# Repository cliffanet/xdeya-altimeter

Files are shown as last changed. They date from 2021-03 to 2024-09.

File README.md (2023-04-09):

# Высотомер "Хде-Йа"

Инструмент для парашютиста - гибрид высотомера и Navi-возвращалки.

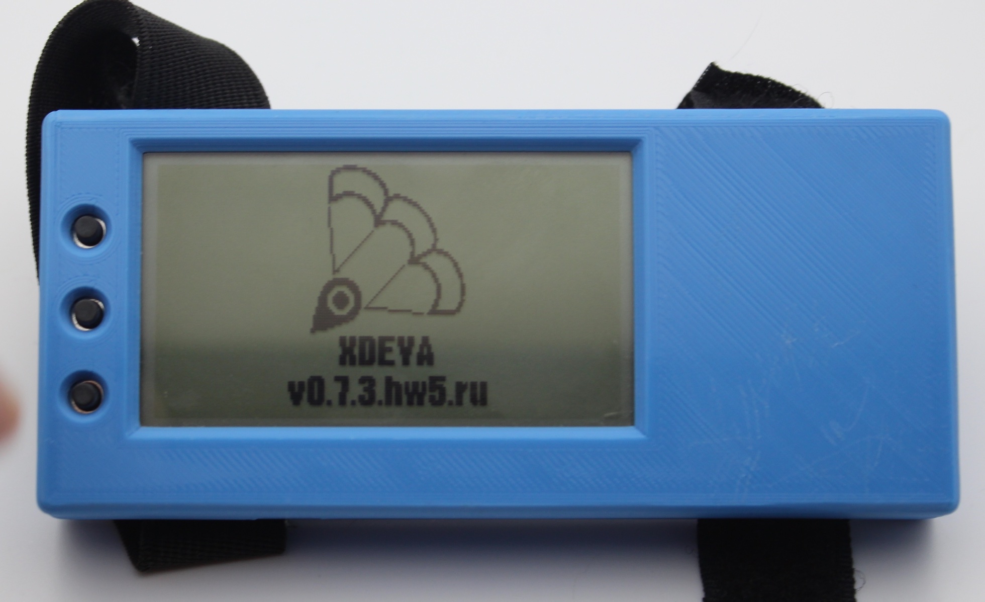
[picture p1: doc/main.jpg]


***
## Возможности

* Классические для высотомера: отображение высоты, логбук и т.д.
* Приём сигнала навигации (GPS + GLONASS)
* Отображение направления и расстояния до заранее сохранённой точки (возвращалка)
* Отображение вертикальной (по барометру) и горизонтальной (по навигации) скоростей
* В логбуке сохраняются показания высотомера и координаты на местности
* Запись трека со всеми имеющимися параметрами барометра и GPS/GLONASS-приёмника
* Взаимодействие с приложением (просмотр логбука, прыжков)

***
## Назначение

* Изначально устройство разрабатывалось как возвращалка в плохих метеоусловиях.

* Студенты, тренирующие точность приземления, смогут на земле разобрать прыжок, имея объективное средство контроля своих перемещений в пространстве.

* Мне как лот организатору групповых прыжков помогало контролировать точку выброски, сильно разгружая голову для остальных функций (взаимодействие с подопечными на борту, дополнительный контроль верности сигналов на выброску), а также помогая объективно оценить задержки выброски из-за неуспевания подготовиться вовремя к отделению.

* Инженеры, программисты микроконтроллеров, использующих Arduino и подобные средства разработки, найдут в этом устройстве полигон для экспериментов в воздухе.

>**Важно:** Устройство не может использоваться для тайного контроля за владельцем, т.к. передача данных вне устройства происходит только по запросу пользователя.

Впрочем, это открытый проект, и каждый может доработать Программное Обеспечение под свои нужды.

***
## Документация

* [Самое краткое руководство](doc/userman/simple/README.md) \[[PDF](doc/userman/xdeya-simple.pdf)|[Word](doc/userman/xdeya-simple.docx)\]
* [Как это сделать?](doc/userman/howdo/README.md) \[[PDF](doc/userman/xdeya-howdo.pdf)|[Word](doc/userman/xdeya-howdo.docx)\]
* [Описание Меню прибора](doc/userman/menu/README.md) \[[PDF](doc/userman/xdeya-menu.pdf)|[Word](doc/userman/xdeya-menu.docx)\]
* [Технические особенности и разъяснения](doc/userman/tech/README.md) \[[PDF](doc/userman/xdeya-tech.pdf)|[Word](doc/userman/xdeya-tech.docx)\]

* [Модификации](doc/models/README.md) - подробное описание аппаратных вариантов и их особенностей с фото.
* [Используемые комплектующие](doc/build/hardware.md)
* [Сколько стоит и где купить](doc/build/price.md)
* [Исходники](doc/code/README.md) - где, что лежит, права на использование, помощь при компиляции.
* [Где скачать](doc/download.md)

***

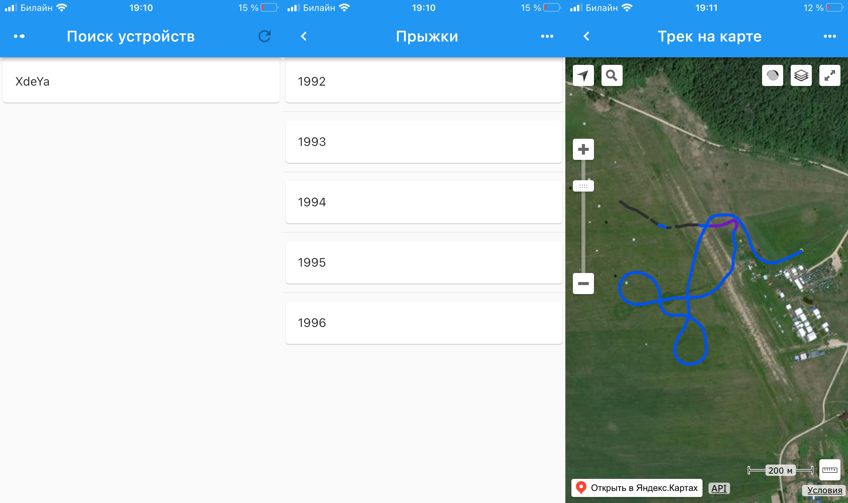
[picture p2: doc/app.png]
Приложение


<video width="475" controls title="demo">
  <source src="doc/demo.mp4" type="video/mp4">
</video>

***
## Контакты

Меня зовут Николай, веду проект `Высотомер + Навигация`. Связаться со мной можно:

* Telegram канал с информацией: [@xdeya](https://t.me/xdeya)
* Telegram: [Cliff](https://t.me/cliffa_net)
* cliff_mail@mail.ru
* Cайт проекта: [xdeya.ru](http://xdeya.ru)

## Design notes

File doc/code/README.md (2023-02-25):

# Хде-Йа - Исходники

## Открытость проекта

Проект полностью открыт. Закрывать - не планирую. На коммерческую основу ставить - не планирую.

Как минимум, для коммерции потребуются согласования по использованию в этом проекте исходного кода других разработчиков, а ещё сертификация использования GPS/GLONASS-приёмника и трекера.

[Репозиторий на github.com](https://github.com/cliffanet/xdeya-altimeter)

## Можно ли использовать исходники в своих проектах

Да, никаких возражений против использования исходного кода в своих проектах. Однако, будет лучше, если вы будете ссылаться на использование данного проекта. Это один из важных мотивационных факторов к дальнейшему развитию.

Это относится и к любительским проектам, и к крупным бесплатным, и к коммерческим.

## Где и что находится

* Исходный код прошивки

    Включает: директорию [`src`](https://github.com/cliffanet/xdeya-altimeter/tree/master/src), файлы [`def.h`](https://github.com/cliffanet/xdeya-altimeter/blob/master/def.h) и [`xdeya-altimeter.ino`](https://github.com/cliffanet/xdeya-altimeter/blob/master/xdeya-altimeter.ino). Для компиляции в среде Arduino нужно только это.
    
    Есть ещё скрипт [`fw`](https://github.com/cliffanet/xdeya-altimeter/blob/master/fw) - он написан на языке [perl](https://www.perl.org/) и служит для удобства компиляции и загрузки прошивки из консоли с помощью утилиты arduino-cli. Про это подробно расписано в подразделе [Как собрать исходный код у себя](#как-собрать-исходный-код-у-себя)

* Исходники электрической схемы и печатной платы

    Всё находится в директории [`hw`](https://github.com/cliffanet/xdeya-altimeter/tree/master/hw). Среда разработки: [KiCad EDA](https://www.kicad.org/)

* Исходники 3D-моделей для печати корпуса

    Директория [`box`](https://github.com/cliffanet/xdeya-altimeter/tree/master/box). Среда: [SketchUp](https://www.sketchup.com/ru)
    
    В имени skp-файла может встречаться `noroundcorner` - это исходник без скруглённых краёв. Оставлен, чтобы было проще поправить, а скругление краёв я всегда делаю в самом конце, т.к. отменить это действие никак нельзя. Файл xdeya.skp - это тот же файл, но  уже конечный вариант со скруглением.
    
    Тут же лежат экспортированные в `stl` файлы моделей. В имени файлов зашифровано:
    
    * `top` / `bottom` - верхняя и нижняя часть корпуса
    * `cord` / `lent` - крепление под эластичный шнур или под эластичную ленту
    * `long` - удлинённый корпус
    * `bold` - утолщённый корпус для более жирного аккумулятора

* Архив
    
    Директория [`arch.hw`](https://github.com/cliffanet/xdeya-altimeter/tree/master/arch.hw). Тут лежат исходники под различные модификации: `плата` (включая gerber-файлы для печати) и `корпус`.

## Электронные компоненты:

* Дисплей JLX19292G: COG 192x96 на чипе ST75256 c 24-pin шлейфом ([например](https://aliexpress.ru/item/1005002157371258.html))

## Как прошить с помощью программатора

### Подключение к компьютеру (версия v.0.3)

Вам потребуется переходник USB-to-UART, т.к. в устройстве его нет. Подойдёт любой с AliExpress.

На плате устройства есть вот такой разъём:

* `gnd` - к `GND` переходника.
* `3v3` - к выходу питания `+3.3v` переходника. Этот вывод можно и не подключать, а питать устройство от аккумулятора или через разъём MicroUSB.
* `tx` - к `RX` переходника.
* `rx` - к `TX` переходника.

При подключении переходника USB-to-UART к компьютеру в списке устройств должен появиться новый последовательный порт (COM-порт). Если этого не произошло, скорее всего, необходимо установить драйверы для этого переходника.

Для программирования данного устройства его надо перевести в download-режим. Для этого удерживая кнопку `boot` на плате устройства, нажмите и отпустите кнопку `reset`. После этого можно отпускать кнопку `boot`.

Теперь устройство готово к загрузке на него прошивки.

### Подключение к компьютеру (версия v.0.4 и более поздние)

У этой модификации на борту уже есть переходник USB-to-UART, поэтому для подключения к компьютеру достаточно подключить его кабелем через разъём MicroUSB на устройстве.

При подключении устройства к компьютеру через USB-кабель, в списке устройств должен появиться новый последовательный порт (COM-порт). Если этого не произошло, потребуется установить драйвер для чипа CP2102 под вашу операционную систему.

Теперь устройство готово к загрузке прошивки.

### Загрузка прошивки на устройство

* Берём [готовый файл](https://github.com/cliffanet/xdeya-altimeter/releases) прошивки (один нужной версии)

* Дополнительные файлы прошивки

    для Flash 4MByte: [boot.zip](https://github.com/cliffanet/xdeya-altimeter/raw/master/boot.zip)

    для расширенной Flash 16Mbyte: [boot.v6.zip](https://github.com/cliffanet/xdeya-altimeter/raw/master/boot.v6.zip)

* Скачиваем и запускаем [Flash Download Tools](https://www.espressif.com/en/support/download/other-tools)

* Нажимаем кнопку `ESP32`

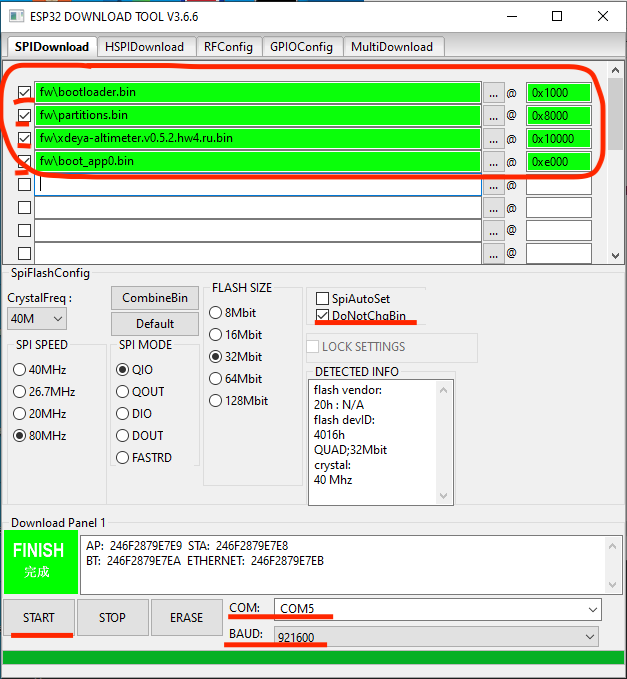
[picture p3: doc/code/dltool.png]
Espressif Flash Download Tools


* Указываем 4 файла и адреса к ним:

    * `bootloader.bin` - адрес 0x1000
    * `partitions.bin` - адрес 0x8000
    * `boot_app0.bin` - адрес 0xe000
    * основной файл прошивки - адрес 0x10000

* Ставим галку DoNotChgBin.

* Выбираем COM-порт, через который подключено устройство.

* BAUD : Это скорость, на которой будет заливаться прошивка. Должна работать любая, в т.ч. максимальная. Но может оказаться, что при высоких скоростях запись будет прерываться.

* Жмем кнопку `START`

После этого начнётся процесс заливки прошивки.

Для аппаратной версии [v.0.3](../models/01.v.0.3.md) для запуска устройства после заливки прошивки требуется нажать кнопку `reset`.

Для аппаратной версии [v.0.4](../models/02.v.0.4.md) ничего дополнительно не требуется.

## Как собрать исходный код у себя

### Используемые сторонние библиотеки для среды Arduino

* [Adafruit_BMP280_Library](https://github.com/adafruit/Adafruit_BMP280_Library)
* [Adafruit_BusIO](https://github.com/adafruit/Adafruit_BusIO) `ver1.9.6` (Необходимая зависимость для Adafruit_BMP280_Library)
* [Adafruit_Unified_Sensor](https://github.com/adafruit/Adafruit_Sensor) (Необходимая зависимость для Adafruit_BMP280_Library)
* [RTClib](https://github.com/adafruit/RTClib)
* [U8g2](https://github.com/olikraus/u8g2)

### В среде Arduino

* Используемая плата: ESP32 Dev Module

    В настройках среды Arduino в поле `Дополнительные ссылки для Менеджера плат` добавить:
    
    https://raw.githubusercontent.com/espressif/arduino-esp32/gh-pages/package_esp32_dev_index.json
    
    В Менеджере плат найти esp32 и установить версию 2.0.0
    
    **ВНИМАНИЕ** В версии 2.0.1 есть бага, при которой повторная WiFi-синхронизация вызывает перезагрузку устройства.

* Откройте в Arduino файл xdeya-altimeter.ino
* Компилируйте, загружайте

### С помощью arduino-cli

Этот способ не работает в Windows, т.к. там нет привычного shell.

Потребуются:

* установленные для Arduino библиотеки
* установленная для Arduino плата
* arduino-cli
* perl

Для компиляции используется скрипт [`fw`](../../fw), который находится в этих исходниках.

Пример запуска:

    ./fw compileupload 4 ru /dev/cu.SLAB_USBtoUART

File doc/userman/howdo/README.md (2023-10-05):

# Хде-Йа - Как это сделать?

## Разделы

* [Включение/Выключение](01.power.md)
* [Навигация](02.navigation.md)
* [Запись трека](03.track.md)
* [Синхронизация](04.syncronization.md)
* [Обновление ПО](05.firmware.md)
* [Системные операции](06.system.md)

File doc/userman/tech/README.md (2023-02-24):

# Хде-Йа - Технические особенности и разъяснения

## Разделы

* [Высотомер](01.altimeter.md)
* [Навигация](02.navigation.md)
* [Режимы питания](03.power.md)

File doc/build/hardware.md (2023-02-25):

# Хде-Йа - Выбранные чипы

## Основной микропроцессор

Сейчас в качестве центрального микроконтроллера используется чипсет [`esp32 wroom`](https://www.espressif.com/en/products/modules/esp32). Он часто применяется в разработках устройств умного дома, поэтому широко известен за свою простоту в использовании.

Причины, по которым изначально выбран именно этот чип:

* Хороший опыт работы с этим микроконтроллером
* Наличие WiFi и BlueThooth на борту
* Большой объём RAM и ROM памяти
* Простота программирования
* Широкое использование начинающими программистами микроконтроллеров (из-за низкого порога вхождения)

Всё это позволяет минимизировать затраты на разработку.

Однако, есть и минусы:

* Большие габариты
* Высокое энергопотребление
* Пока ещё сырое SDK от разработчиков чипа, особенно в области низкого энергопотребления и WiFi/BlueTooth

## Навигация

В данном устройстве используется навигационный чип [u-blox M8N](https://www.u-blox.com/en/product/neo-m8-series). Чип настроен на приём GPS и GLONASS сигналов.

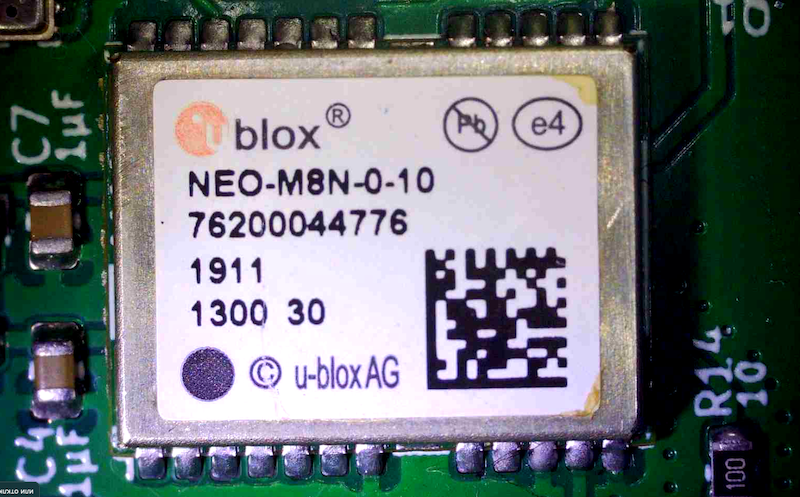
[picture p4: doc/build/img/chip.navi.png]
u-blox M8N


## Барометр

Для определения высоты применён барометрический чип [BMP280](https://www.bosch-sensortec.com/products/environmental-sensors/pressure-sensors/bmp280/), зарекомендовавший себя при разработке высотомеров у многих проектировщиков таких устройств.

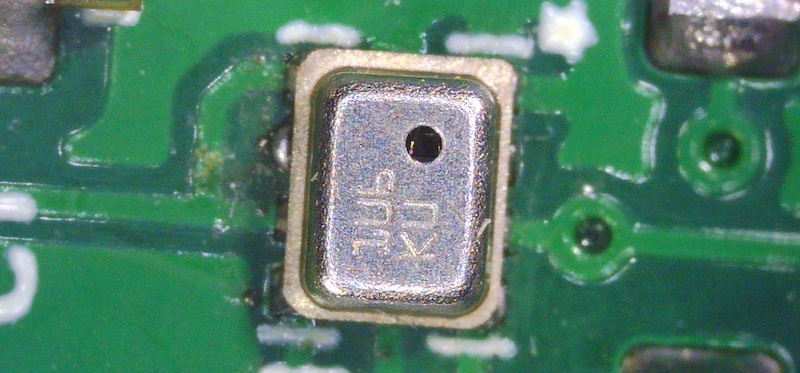
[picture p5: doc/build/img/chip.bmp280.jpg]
BMP280


## Компас

Используемый чип: LSM303DLH (именно с такими буквами, в корпусе LGA-28L).

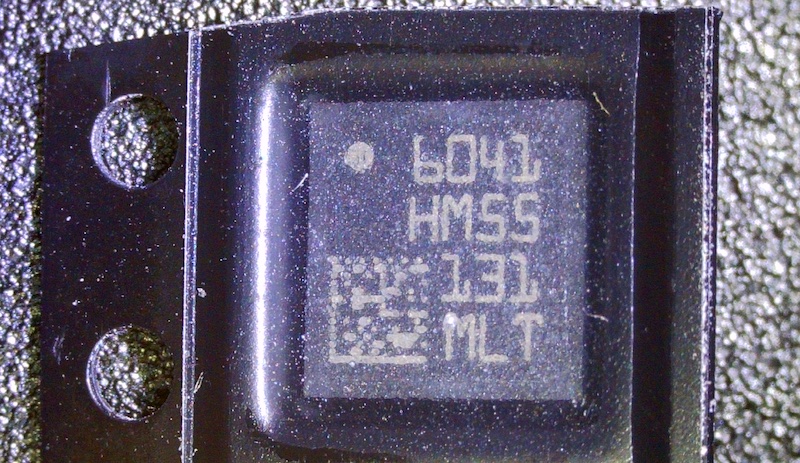
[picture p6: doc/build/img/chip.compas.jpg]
LSM303DLH


В его составе:

* Магнетометр - для определения вектора магнитных линий земли.
* Акселерометр - для определения положения прибора относительно Земли, чтобы корректно спроецировать вектор магнитного поля на поверхность Земли.

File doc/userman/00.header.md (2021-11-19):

---
title: "Хде-Йа - Руководство пользователя"
author: Cliff
geometry: margin=1.5cm
mainfont: Arial
monofont: PT Mono
toc-title: Оглавление
colorlinks:
    urlcolor: NavyBlue
    toccolor: Red
subparagraph: true
lang: ru-RU
---

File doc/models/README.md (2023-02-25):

# Хде-Йа - Разновидности устройств

На данный момент есть несколько вариантов устройств. Для каждого разработана своя плата, компановка деталей, корпус.

[Исходники](../code/README.md) всей технической документации можно скачать и использовать.

* [`v.0.3`](01.v.0.3.md) (более не поддерживается)
* [`v.0.4`](02.v.0.4.md) (более не поддерживается)
* [`v.0.5`](03.v.0.5.md)

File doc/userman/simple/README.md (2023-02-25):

# Знакомство

Вы никогда не задавались вопросом:

> И `хде йа` нахожусь?!

Или может в 2 часа ночи интересовались:

> Как пройти в библиотеку?

**Привет!**

Я - `высотомер` и `GPS/GLONASS` в одном приборе.

Я `**НЕ**` являюсь навигатором. Только возвращалкой к заранее заданной точке. Покажу направление и расстояние до точки по прямой.

Пока я ещё как эксперементальная разработка. Жить этому проекту или нет, выберете Вы сами.

А по карте маршрут вам проложит Яндекс Навигатор, но не я!

## Функции устройства

* Классические для высотомера: отображение высоты, логбук и т.д.
* Приём сигнала навигации (GPS + GLONASS)
* Отображение направления и расстояния до заранее сохранённой точки (возвращалка)
* Отображение вертикальной (по барометру) и горизонтальной (по навигации) скоростей
* В логбуке сохраняются показания высотомера и координаты на местности
* Запись трека со всеми имеющимися параметрами барометра и GPS/GLONASS-приёмника
* Синхронизация по WiFi (по запросу пользователя): отправка логбука, треков, приём некоторых настроек с сервера

# Диаграмма управления

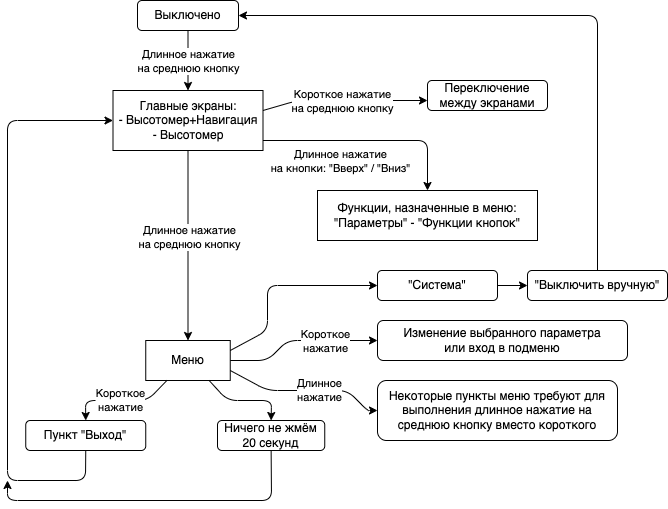
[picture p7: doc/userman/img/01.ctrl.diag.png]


# Органы управления

Переключение между страницами на главном экране - нажатие на `среднюю кнопку`.

Кнопки `Вверх` и `Вниз` работают только по `длинному нажатию`, их функциями можно управлять в меню `Параметры` -> `Функции кнопок`.

##  Экран: Навигация + Высотомер

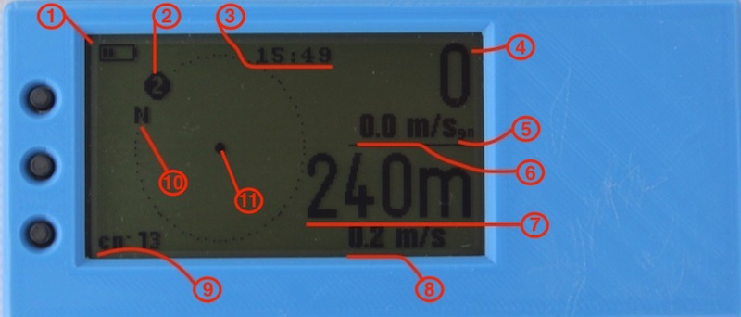
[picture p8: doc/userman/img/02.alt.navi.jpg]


1. Индикатор заряда батареи.
2. Относительное отображение расположение точки.
3. Текущее время (синхронизируется по GPS/GLONASS-сигналу).
4. Высота по барометру (метры).
5. Временное отображение режима высотомера (по текущей высоте, скорости и вертикальному направлению движения).
6. Вертикальная скорость (м/с).
7. Расстояние до выбранной точки (метры или километры).
8. Горизонтальная скорость.
9. Режим работы Navi приёмника (во включенном состоянии отображает число найденных спутников).
10. Условное обозначение "Севера".
11. Центр карты: тут мы, при движении рисуется стрелка - чем быстрее, тем длиннее.

##  Экран: Навигация

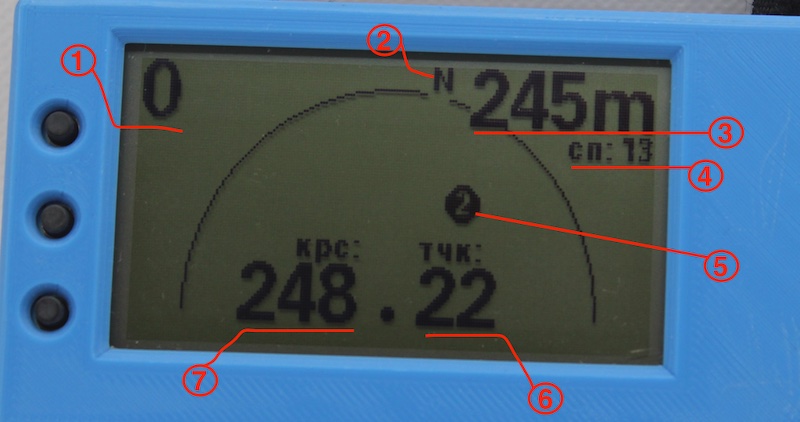
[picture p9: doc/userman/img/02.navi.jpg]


1. Высота по барометру (метры).
2. Условное обозначение "Севера".
3. Расстояние до выбранной точки (метры или километры).
4. Режим работы Navi приёмника (во включенном состоянии отображает число найденных спутников).
5. Относительное отображение расположение точки.
6. Направление до точки (в градусах).
7. Направление движения (в градусах).

## Экран: Высотомер

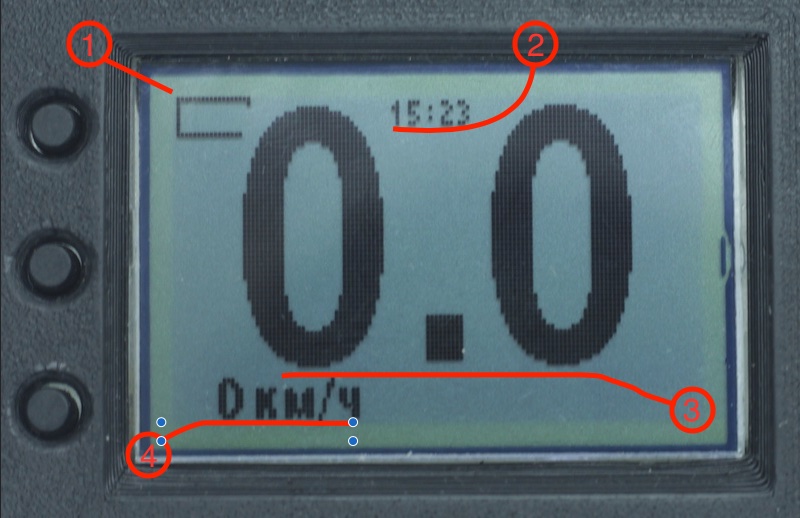
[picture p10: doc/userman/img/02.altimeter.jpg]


1. Индикатор заряда батареи.
2. Текущее время (синхронизируется по GPS/GLONASS-сигналу).
3. Высота по барометру (километры).
4. Вертикальная скорость (км/ч).

# Как вбить конечную точку

Меню: `Navi-точки` - выбираем из трёх слотов хранения координат и сохраняем текущее местоположение.

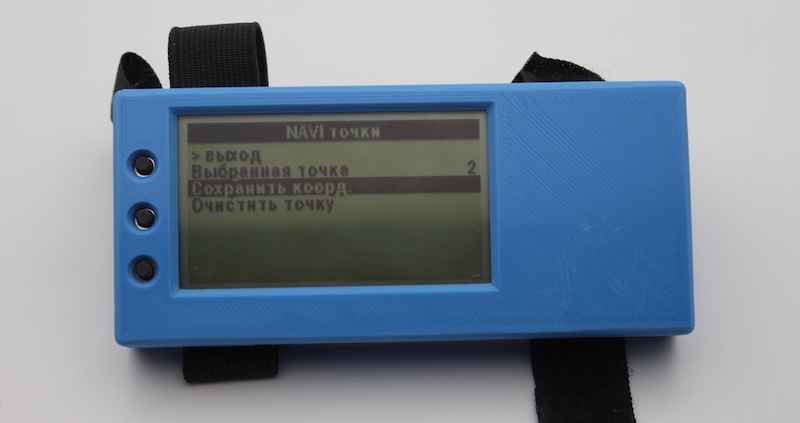
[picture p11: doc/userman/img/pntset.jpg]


# Как заряжать

В это отверстие вставляем USB-шнурок одним концом, а другим в зарядку или ваш домашний компьютер:

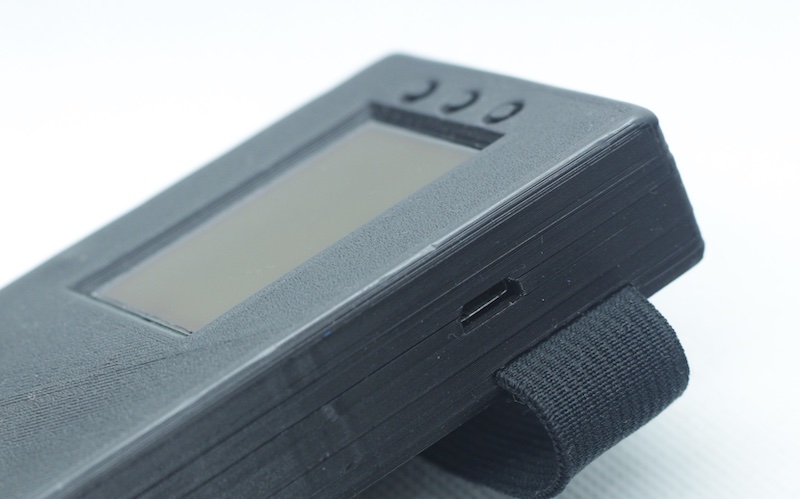
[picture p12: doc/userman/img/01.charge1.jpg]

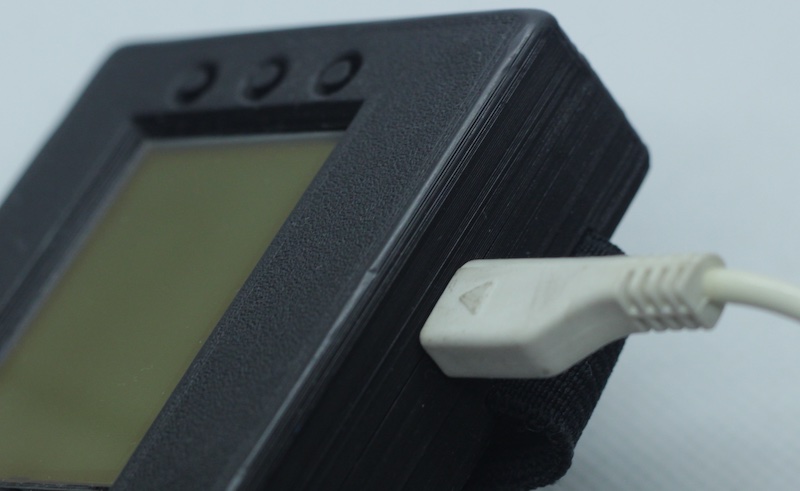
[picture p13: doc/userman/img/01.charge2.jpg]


# Крепление

* На руку

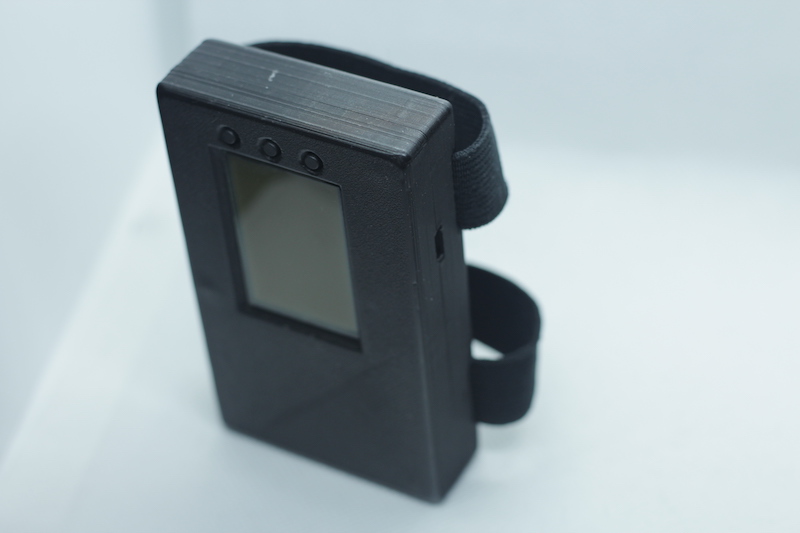
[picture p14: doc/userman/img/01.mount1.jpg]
Крепление на руку


* На ногу

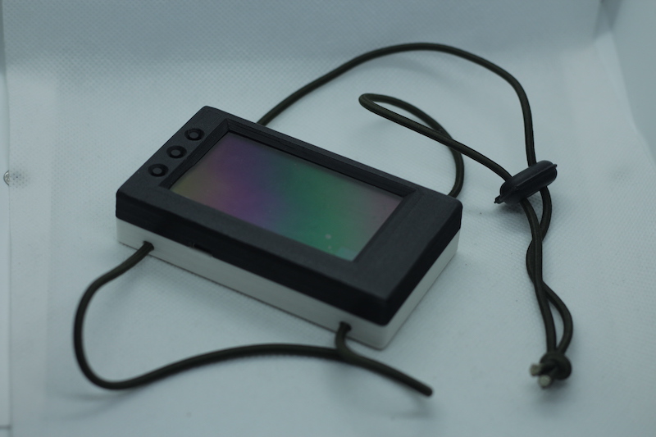
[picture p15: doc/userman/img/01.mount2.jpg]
Крепление на ногу


# Подсветка

Меню: `Параметры` -> `Дисплей` -> `Подсветка`

Для ночных прыжочков:

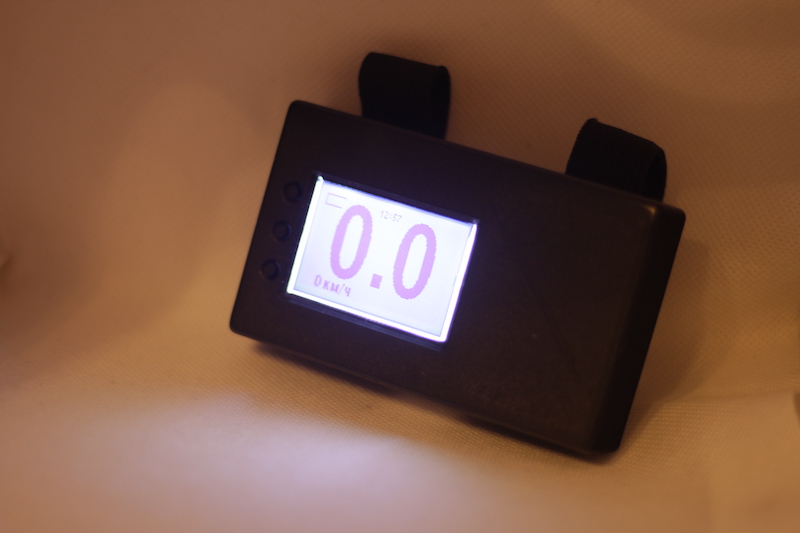
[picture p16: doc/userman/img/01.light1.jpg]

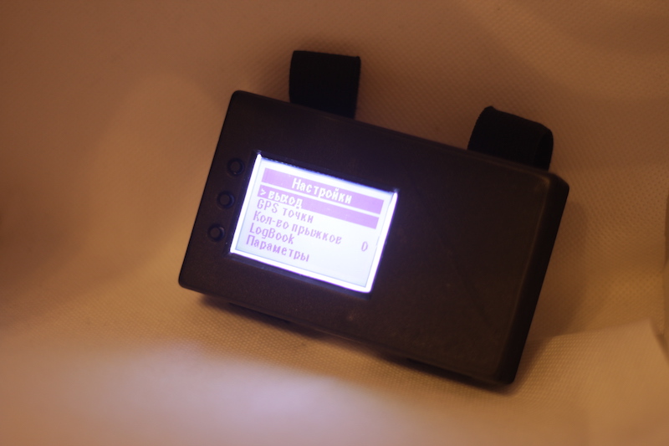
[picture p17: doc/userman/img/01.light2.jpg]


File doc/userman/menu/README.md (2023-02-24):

# Хде-Йа - Меню прибора

В данном документе представлено описание меню прибора.

Вход в меню настроек осуществляется длинным нажатием на `среднюю кнопку` из `главных экранов`.

Выход обратно в главные экраны:

* Вручную - через пункт меню `Выход/Exit`.
* Автоматически - через 15 секунд, если не нажимать никаких кнопок.

Перемещение по пунктам меню - с помощью кнопок `Вверх` и `Вниз`

Некоторые пункты, где указано значение параметра справа, можно редактировать: нажимаем однократно `среднюю кнопку`, кнопками `вверх` и `вниз` меняем `значение` и завершаем редактирование повторным нажатием на `среднюю кнопку`. Пункты, имеющие только два варианта: `да` и `нет` - меняются простым одинократным нажатием на `среднюю кнопку`.

Меню имеет древовидную структуру. В более глубокий уровень заходим через однократное нажатие средней кнопки. Уровнем выше поднимаемся через пункт меню "Выход"/"Exit" - он всегда в самом верху списка.

## Разделы

* [NAVI-точки](01.navipoint.md)
* [Количество прыжков](02.jumpcount.md)
* [LogBook](03.logbook.md)
* [Параметры](04.option.md)
* [Система](05.system.md)
* [Сохронизация](06.sync.md)

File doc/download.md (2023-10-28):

# Скачивание файлов

Стабильная версия прошивки (только для [`v.0.5`](models/03.v.0.5.md)):

* RU: [xdeya-altimeter.v0.7.7.hw5.ru.bin](https://github.com/cliffanet/xdeya-altimeter/releases/download/v0.7.7/xdeya-altimeter.v0.7.7.hw5.ru.bin)
* EN: [xdeya-altimeter.v0.7.7.hw5.en.bin](https://github.com/cliffanet/xdeya-altimeter/releases/download/v0.7.7/xdeya-altimeter.v0.7.7.hw5.en.bin)

## Как обновить прошивку

* Скачиваем нужную версию (bin-файл)
* Сохраняем bin-файл в корень SD-карты
* Вставляем SD-карту в прибор
* Меню: `Система` -> `Обновление прошивки` -> `Обновить с SD-карты`
* Выбираем нужный файл и жмём среднюю кнопку

## Приложение

- Windows

    [xdeya.v0.7.6.zip](https://github.com/cliffanet/xdeya-altimeter/releases/download/v0.7.6/xdeya.v0.7.6.zip)

- MacOS

    [xdeya.v0.7.6.dmg](https://github.com/cliffanet/xdeya-altimeter/releases/download/v0.7.6/xdeya.v0.7.6.dmg)

- Android

    [xdeya.v0.7.6.apk](https://github.com/cliffanet/xdeya-altimeter/releases/download/v0.7.6/xdeya.v0.7.6.apk)

- iOS

    (https://apps.apple.com/app/xde-ya/id6445976117)

## Как подключиться из приложения

* При первом подключении требуется WiFi-сеть без пароля.

    * Начиная с версии прошивки `v0.7.5`, можно использовать
    WiFi-сеть с паролем "по умолчанию": z12344321

* Подойдёт любая сеть - на домашнем роутере или на мобильном телефоне.
* Меню: `Синхронизация` -> `Приложение по WiFi`
* Выбираем нужную сеть - и телефон (или компьютер), и прибор должны быть подключены к одной сети.
* После этого прибор должен появится в списке устройств в приложении
* При подключении в приложении необходимо ввести буквы-цифры на экране прибора

## История версий

[История версий и самые свежие файлы](https://github.com/cliffanet/xdeya-altimeter/releases)

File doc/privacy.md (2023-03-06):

# Политика конфиценциальности

## Русский

Политика конфиденциальности

* Термин “личная информация”, используемый в настоящем документе, определяется как любая информация, которая идентифицирует или может использоваться для идентификации, связи или поиска человека, к которому такая информация относится. Личная информация, которую мы собираем, будет являться предметом настоящей политики конфиденциальности, с вносимыми время от времени поправками.
*  Мы не запрашиваем Ваш адрес электронной почты, телефон или какую нибудь информацию о Вас.
* Мы не продаем контент.
* Мы не требуем регистрации.
* Безопасность Вашей персональной информации не будет нарушена.
* Мы не просим информацию о местоположении через наше мобильное приложение.
* Мы не отправляем на электронную почту рассылку новостей.

Контакты

Telegram: [Cliff](https://t.me/cliffa_net)

## En

Privacy Policy

Built the AppName app as a Free app. This service is provided by at no cost and is intended for use as is.

Contact Us

If you have any questions or suggestions about my Privacy Policy, do not hesitate to contact me Telegram: [Cliff](https://t.me/cliffa_net).

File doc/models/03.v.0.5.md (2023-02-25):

# Хде-Йа - Модификация v.0.5

Данная версия пока только в стадии проектирования.

## Особенности (отличия от [`v.0.4`](02.v.0.4.md))

* Наличие подключаемой SD-карты для хранения треков и прыжков
* Аппаратный компас
* Антенна навигации вынесена из-под дисплея для лучшего приёма
* Возможность выноса внешней антенны (такой вариант корпуса пока не прорабатывался за ненадобностью)

## Внешний вид

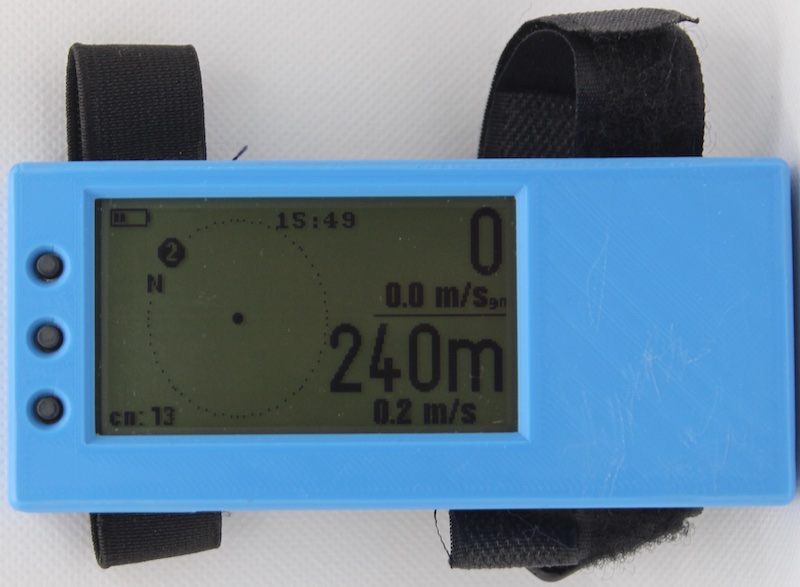
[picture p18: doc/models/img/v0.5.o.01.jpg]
Внешний вид (v.0.4)


## Внутренности

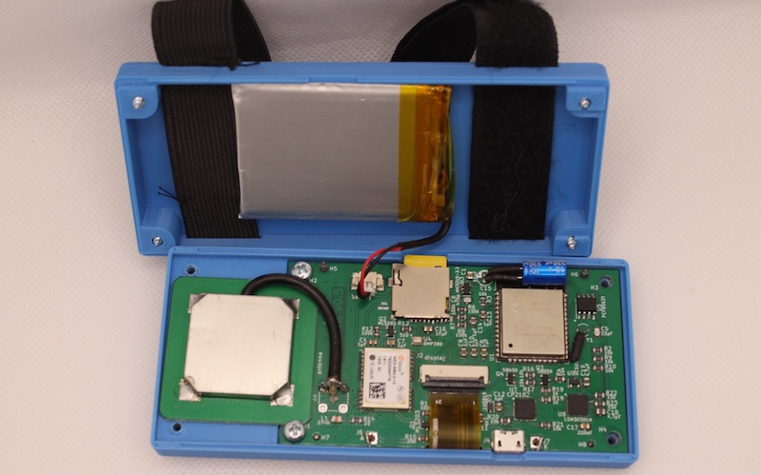
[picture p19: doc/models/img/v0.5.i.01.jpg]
Внутренности (v.0.4)


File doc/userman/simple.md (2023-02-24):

---
title: "Хде-Йа - Самое краткое руководство"
author: Cliff
geometry: margin=1.5cm
mainfont: Arial
monofont: PT Mono
toc-title: Оглавление
colorlinks:
    urlcolor: NavyBlue
    toccolor: Red
subparagraph: true
lang: ru-RU
---

# Знакомство

Вы никогда не задавались вопросом:

> И `хде йа` нахожусь?!

Или может в 2 часа ночи интересовались:

> Как пройти в библиотеку?

**Привет!**

Я - `высотомер` и `GPS/GLONASS` в одном приборе.

Я `**НЕ**` являюсь навигатором. Только возвращалкой к заранее заданной точке. Покажу направление и расстояние до точки по прямой.

Пока я ещё как эксперементальная разработка. Жить этому проекту или нет, выберете Вы сами.

А по карте маршрут вам проложит Яндекс Навигатор, но не я!

## Функции устройства

* Классические для высотомера: отображение высоты, логбук и т.д.
* Приём сигнала навигации (GPS + GLONASS)
* Отображение направления и расстояния до заранее сохранённой точки (возвращалка)
* Отображение вертикальной (по барометру) и горизонтальной (по навигации) скоростей
* В логбуке сохраняются показания высотомера и координаты на местности
* Запись трека со всеми имеющимися параметрами барометра и GPS/GLONASS-приёмника
* Синхронизация по WiFi (по запросу пользователя): отправка логбука, треков, приём некоторых настроек с сервера

# Диаграмма управления



# Органы управления

Переключение между страницами на главном экране - нажатие на `среднюю кнопку`.

Кнопки `Вверх` и `Вниз` работают только по `длинному нажатию`, их функциями можно управлять в меню `Параметры` -> `Функции кнопок`.

##  Экран: GPS/GLONASS + Высотомер

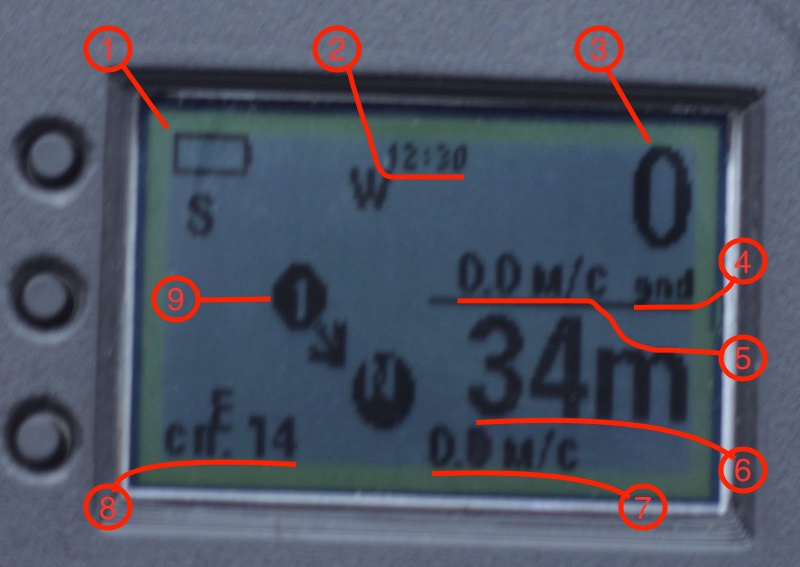
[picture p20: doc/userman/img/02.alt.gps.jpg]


1. Индикатор заряда батареи.
2. Текущее время (синхронизируется по GPS/GLONASS-сигналу).
3. Высота по барометру (метры).
4. Временное отображение режима высотомера (по текущей высоте, скорости и вертикальному направлению движения).
5. Вертикальная скорость (м/с).
6. Расстояние до выбранной точки (метры или километры).
7. Горизонтальная скорость.
8. Режим работы GPS/GLONASS приёмника (во включенном состоянии отображает число найденных спутников).
9. Номер выбранной точки и направление к ней.

Буквы `N` `S` `W` `E` - означают стороны света, как на компасе.

## Экран: Высотомер



1. Индикатор заряда батареи.
2. Текущее время (синхронизируется по GPS/GLONASS-сигналу).
3. Высота по барометру (километры).
4. Вертикальная скорость (км/ч).

# Как вбить конечную точку

Меню: `Navi-точки` - выбираем из трёх слотов хранения координат и сохраняем текущее местоположение.

Тут должна быть картинка

# Как заряжать

В это отверстие вставляем USB-шнурок одним концом, а другим в зарядку или ваш домашний компьютер:

USB
USB

# Крепление

* На руку

Крепление на руку

* На ногу

Крепление на ногу

# Подсветка

Для ночных прыжочков:

Подсветка
Подсветка

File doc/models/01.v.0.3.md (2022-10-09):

# Хде-Йа - Модификация v.0.3

Экран у этой модификации не очень большой, но это позволило максимально открыть GPS/GLONASS-антенну.

## Особенности

* Небольшой размер экрана (диагональ: 4,5 см)
* Большие поля у корпуса
* NAV-антенна прикрыта только корпусом, но из-за этого рядом с экраном на корпусе большая пустующая область
* USB-разъём только для зарядки
* Для прямого программирования нужен переходник usb-uart

## Внешний вид

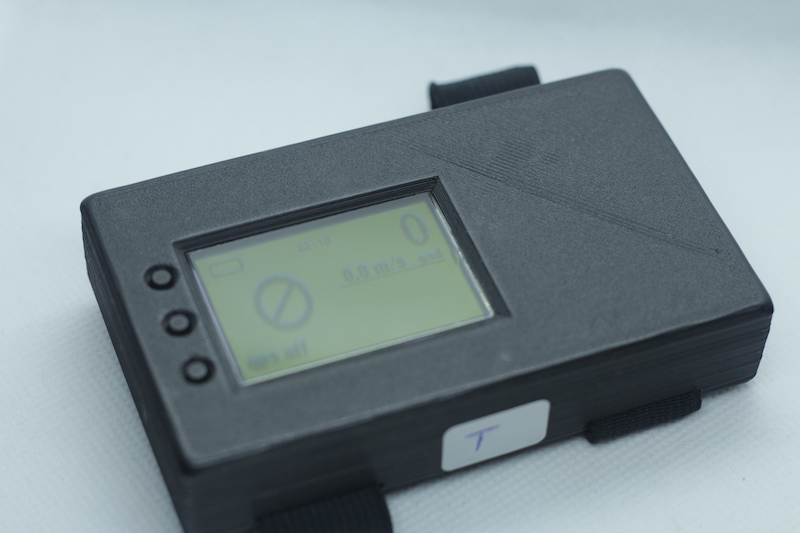
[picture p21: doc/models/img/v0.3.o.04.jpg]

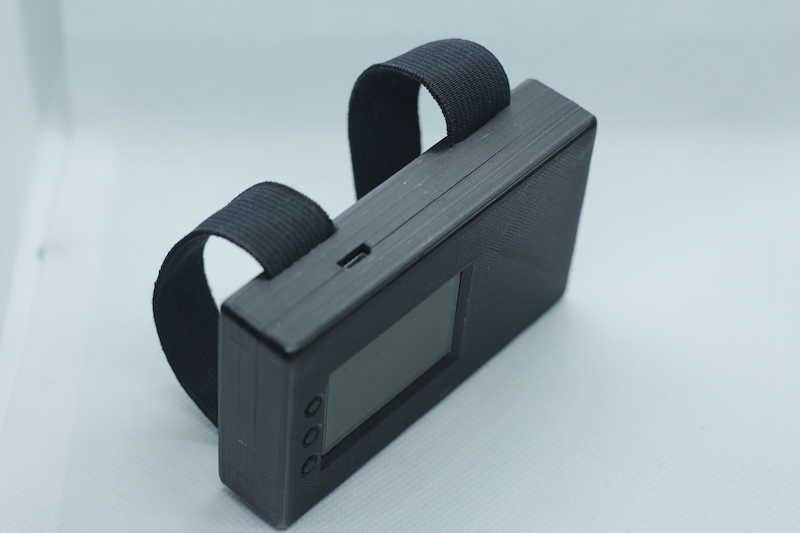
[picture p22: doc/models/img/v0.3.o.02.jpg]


## Внутренности

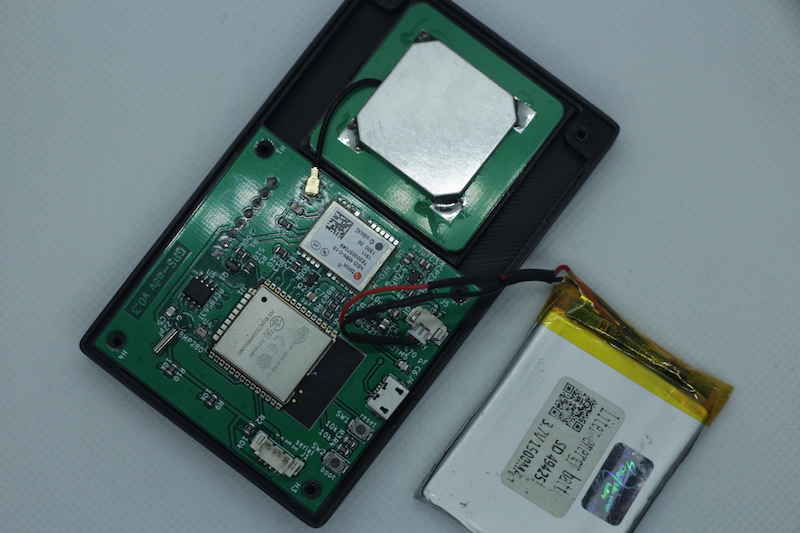
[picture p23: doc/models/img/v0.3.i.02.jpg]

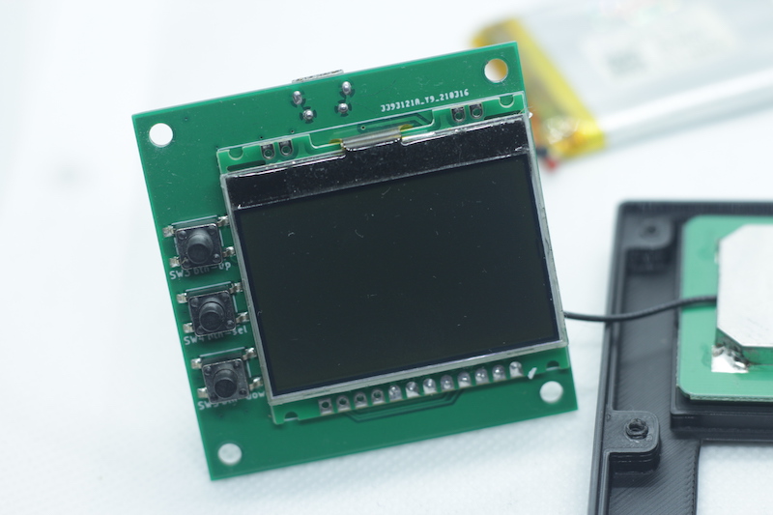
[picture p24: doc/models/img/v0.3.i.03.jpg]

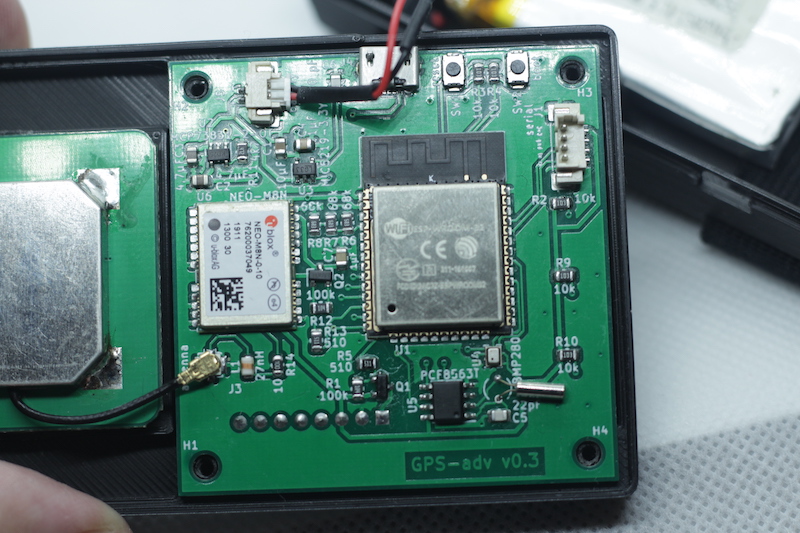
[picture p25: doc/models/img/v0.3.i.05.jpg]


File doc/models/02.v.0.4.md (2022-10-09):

# Хде-Йа - Модификация v.0.4

Основное преимущество этой модификации - большой экран.

Однако, ради этого в жертву пришлось отдать качество приёма.

## Особенности (отличия от [`v.0.3`](01.v.0.3.md))

* Больший размер экрана, почти на всю поверхность грани корпуса (диагональ: 7,5 см)
* Небольшие поля у корпуса
* NAV-антенна прикрыта на две трети экраном, это сильно ухудшило качество приёма
* Программирование возможно по USB-разъёму

## Внешний вид

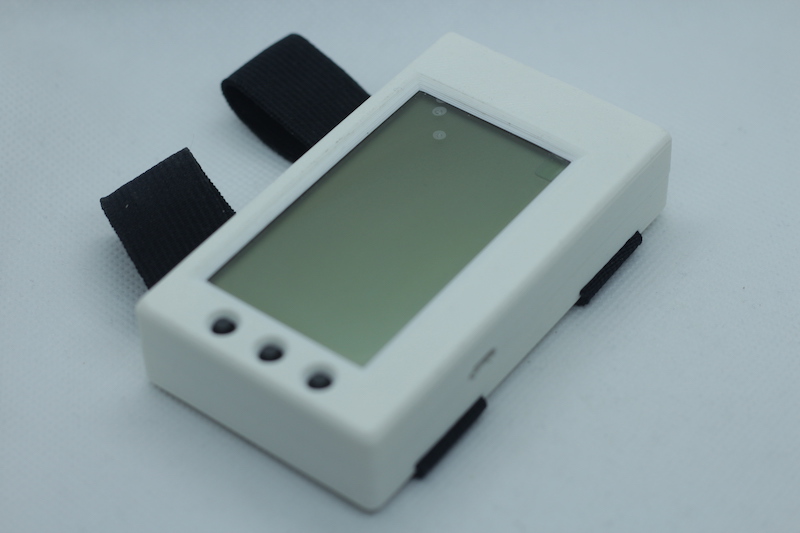
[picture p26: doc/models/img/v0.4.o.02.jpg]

Внешний вид (v.0.4)

## Внутренности

Внутренности (v.0.4)
Внутренности (v.0.4)
Внутренности (v.0.4)
Внутренности (v.0.4)

## Другой вариант крепления (на ногу)

Вариант крепления на ногу (v.0.4)

## Удлинённый вариант

Попытка вынести антенну на этой версии за пределы дисплея. Размеры прибора получились довольно большими. И из-за этого он стал менее удобен.
Но в этом случае уровень сигнала существенно лучше.

Удлинённый вариант (v.0.4)

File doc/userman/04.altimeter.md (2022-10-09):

# Высотомер

Как и во всех других высотомерах, для определения текущей высоты применяется датчик давления.

## Датчик

Используемый датчик давления: BMP280.

Этот датчик хорошо зарекомендовал себя во многих проектах многочисленных разработчиков высотомеров и пищалок.

У него очень низкое энергопотребление, высокая скорость ответа, миниатюрные размеры, простота монтажа.

На плате датчик выглядит так:

Датчик давления на плате

## Калибровка высоты по текущему давлению

Устройство самостоятельно подстраивает давление нулевой высоты, пока Вы находитесь на земле.

Автоматическую подстройку можно отключить через `меню настроек`. Однако, в этом случае в течение дня определение высоты может уходить на 10, 20 или даже 50 метров в ту или другую сторону.

Если вы поднимитесь на высоту `40 м` и более, автоматическая подстройка будет отключена до момента, пока вы не вернётесь обратно на нулевой уровень.

В случае, если после приземления высотомер будет показывать более 40 метров и из-за этого не будет корректироваться, Вы можете сами вручную сбросить `уровень земли` через `меню настроек`.

## Сложности вычисления высоты по барометру

Основной проблемой для любых приборов, измеряющих высоту по барометру, являются зоны турбулентности и зоны повышенного давления. Особенно заметно это проявляется на скоростях `более 20 м/с` в любом направлении.

**Зоны турбулентности** встречаются достаточно часто:

* В летательном аппарате - это обычно зона у открытой двери.
* В свободном падении существенно турбулентный поток возникает над рукой, на которой закреплён высотомер.

**Зона повышенного давления** формируется в двух случаях:
* если измеряющее давление устройство находится под телом в непосредственной близости от него в свободном падении;
* в салоне самолёта, если размеры двери небольшие по сравнению с объёмом салона.

Например, в инструкциях ко многим страхующим приборам в явном виде это описано. И указывается, что в положении на животе (когда прибор находится в зоне пониженного давления на спине) прибор сработает на `80 метров` ниже, чем в положении на спине (когда прибор находится в зоне повышенного давления).

В некоторых случаях погрешность показаний может достигать `более ±100 метров`. Помните об этом при учёте показаний с подобных приборов, в т.ч. и этого.

Вот пример замера высоты в момент отделения с ЛА с боковой дверью. Поля: время в мс, высота по барометру и высота по GPS/GLONASS (над уровнем моря). Частота замеров - 10 раз в секунду, однако, данные с NAV-приёмника идут 5 раз в секунду.

    3294		3991		4288
    3396		3989		4287
    3494		3993		4287
    3596		3989		4285
    3694		3987		4285
    3796		3994		4283
    3894		4010		4283
    3996		4002		4282    <-- Примерно тут высотник оказался за обрезом
    4093		4025		4282
    4197		4009		4279
    4293		4044		4279
    4395		4056		4277
    4493		4064		4277
    4595		4063		4274
    4692		4072		4274
    4794		4035		4272
    4892		4071		4272
    4994		4085		4268
    5092		4107		4268
    5196		4100		4265    <-- Примерно тут уже началось падение
    5292		4087		4265
    5394		4075		4261
    5492		4065		4261
    5594		4044		4257
    5691		4027		4257
    5793		4013		4253
    5890		4006		4253
    5992		4011		4249
    6090		4023		4249
    6194		4009		4243
    6290		4014		4243
    6392		4010		4238
    6489		3996		4238
    6591		4022		4232
    6688		4015		4232
    6790		4019		4226
    6888		4000		4226
    6990		4009		4220
    7087		4050		4220
    7191		4050		4214
    7287		4048		4214
    7389		4039		4207
    7486		4021		4207

Далее показания высоты уменьшались более последовательно.

График замеров текущей высоты

Приведён пример отделения горизонтальной 8-way в захватах из самолёта Л-410. Устройство было на руке участника, отделяющегося из салона. А отделение мы завалили :smile:. Если устройство повесить на руку, отделяющегося снаружи, там всё ещё веселее.

Всё это создаёт значительные трудности в определении момента отделения. У высотомеров более известных брендов трудности те же самые, именно поэтому не стоит сильно доверять показаниям в вашем логбуке.

Напрашивается сразу же предложение - ориентироваться на GPS/GLONASS. Но обычно на отделении, особенно пока вывешиваемся и берём друг друга за захваты, в этот момент сигнал теряется и возобновляется только через какое-то время после отделения.

## Алгоритм определения фаз прыжка

В отличие от более простых высотомеров, где не так критична точность определения начала прыжка, в этом устройстве при начале прыжка требуется засечь текущие координаты и включить запись трека. Если точность определения прыжка будет низкой, полезность данного устройства будет сомнительной.

1. Каждый прыжок должен начинаться с подъёма. Эта фаза включается, когда примерно 5 секунд продолжается набор высоты. Без этой фазы все остальные невозможны.

2. Снижение может возникать по многим причинам:
    - удержание полёта на одном эшелоне,
    - временное снижение ЛА,
    - снижение некоторых ЛА при сбросе газа `на боевом`,
    - резкие изменения давления.
    
    Поэтому для однозначного определения, что это именно отделение, скорость снижения дожна быть не менее 15 м/с на протяжении 5 секунд. В этом случае принимается решение, что это всё-таки отделение и падение.
    
    Моментом отделения считается тот, что был 5 сек назад на момент принятия решения. Опыты показали, что это максимально близко к правде, если отделяться изнутри салона. Если сначала вывешиваться за бортом, то ошибка определения момента отделения достигает 2 сек.

3. Теперь надо решить, открыли ли мы парашют под бортом или падаем в свободном падении. Если за последующие 3 секунды скорость снижения достигнет 35 м/с, считается, что прыжок начался со свободного падения. Иначе, в логбук будет записано нулевое время свободного падения.

4. Если у нас всё-таки случилась фаза свободного падения, то она завершится, если около 6 секунд скорость снижения будет ниже 12 м/с. Моментом открытия будет тот, что был 6 секунд назад перед принятием решения.

5. Момент приземления - если высота ниже 50 метров сохраняется более 6 секунд.

Для того, чтобы в логбук писать верные значения, т.к. определение моментов начала каждой фазы происходит с опозданием в несколько секунд, ведётся непрерывный лог параметров на протяжении прошедших 10 секунд. И после принятия решения для каждой фазы нетрудно получить параметры начала фазы.

Этот алгоритм показал стабильный и достаточно точный результат. Однако, иногда фаза свободного падения не засчитывается.

Иногда на выброске ЛА длительное время достаточно интенсивно снижается. Обычно пилоты намеренно начинают снижение на выброске, чтобы не допустить свала. Однако, это может привести к ошибочному принятию решения о моменте начала прыжка.

При достаточно большой статистике, подтверждённой средствами объективного контроля, получится доработать алгоритм для получения более точных показаний. Для этого достаточно присылать трек прыжка вместе с видео этого прыжка разработчикам с пометкой: `для доработки алгоритма определения прыжка`.

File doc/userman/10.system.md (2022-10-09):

# Системные операции

Все системные операции находятся в меню `Система`. Всё, кроме `Обновления ПО` и `Отключения питания` требуется, как правило, только в случаях нештатной работы устройства.

## Отключение питания

На данный момент одной из основных проблем устройства является потребление энергии от аккумулятора. При этом устройство при полностью активном режиме может разрядиться меньше, чем за один световой день.

* В меню `Система` -> `Выключить питание` или в меню `Автовыключение` -> `Выключить вручную`.

`Длинным нажатием` на `среднюю кнопку` выключает питание устройства.

На деле же, устройство не отключается от источника питания (аккумулятора). Центральный процессор переходит в `режим глубокого сна`, дисплей переходит в режим энергосбережения, микроконтроллер NAVI отключается от питания полностью, а барометр остаётся подключенным к источнику питания - его энергопотребление минимально.

Работа центрального процессора ограничивается слежением за нажатием на кнопки, чтобы включить устройство обратно.

Обратно устройство включается `Длинным нажатием` на `среднюю кнопку`.

## Перезагрузка

Перезагрузка устройства требуется в очень редких и особых случаях. При штатной работе она не должна требоваться.

В меню `Система` -> `Выключить питание` - `Длинным нажатием` на `среднюю кнопку`.

## Сброс всех настроек

Все данные на устройстве хранятся в файлах.

Сброс всех настроек фактически удаляет все файлы, включая:

* настройки
* привязку к Web-аккаунту
* список паролей к WiFi-сетям
* логбук
* записанные треки

В меню `Система` -> `Сброс всех настроек` - `Длинным нажатием` на `среднюю кнопку`.

## Файлы

Все данные на устройстве хранятся в файлах. Управлять ими можно в меню `Система` -> `Файлы`.

`Длинным нажатием` на `среднюю кнопку` можно удалить выбранный файл.

`Логбук` и `Треки` хранятся в пронумерованных файлах. Если удалить один из них, чтобы восстановить последовательность нумерации, необходимо `Длинным нажатием` на `среднюю кнопку` на пунктах `перенумерование логбук-файлов` или `перенумерование треков` соответственно.

## Нав: serial

Включение режима NAV-serial позволяет управлять микропроцессором NAV-приёмника через серийный порт устройства.

## Нав: Холодный перезапуск

Выполняет холодный перезапуск NAV-приёмника, при котором будет сброшен список спутников.

## Тестирование аппаратуры

Этот раздел позволяет проверить корректность работы узлов устройства.

* Часы - Даже если не синхронизированы, время должно идти, а не стоять на месте.
* Напряжение на батарее - Показывет текущее рассчитанное напряжение, должно быть в пределах `3.0-4.2 Вольт`.
* Заряжается ли батарея - При подключении USB-зарядки должно отображать `Да`.
* Показания барометра - Текущее атмосферное давление, должно быть в пределах `9-11 кПа`.
* Подсветка экрана - Включает подсветку по длинному нажатию на `среднюю кнопку` и через секунду подсветка отключается.
* Данные с NAV-приёмника - Показывает задержку в приёме данных, она не должна превышать `500 мс`.
* Перезапуск по питанию микропроцессора NAV-приёмника -  По `длинному нажатию` на `среднюю кнопку`.
* Повторная инициализация NAV-приёмника - требуется, если NAV-приёмник был перезапущен пунктом выше.

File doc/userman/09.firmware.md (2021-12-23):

# Обновление ПО

Обновление прошивки - системная процедура, которая может быть выполнена пользователем без опаски.

Т.к. связь с сервером осуществляется только при Wi-Fi синхронизации, то обновление прошивки происходит при той же процедуре.

Т.к. процедура обновления прошивки может надолго занять устройство и не дать им пользоваться, она никогда не происходит автоматически.

Запрос на обновление прошивки происходит в меню `Система` -> `Обновление ПО`. Там в пункте `Обновить до` выбираем нужную версию и переходим в меню `Синхронизация`.

Если версия прошивки анонсирована, но её нет при выборе версии, то необходимо перед выбором версии произвести синхронизацию, чтобы список версий обновился.

**ВАЖНО!** Если во время обновления прошивки произошёл сбой, то перед повторной синхронизацией необходимо либо `перезагрузить` устройство, либо `выключить`-`включить`. Без перезагрузки возможно продолжение штатной работы устройства, проблема будет только при синхронизации (на этапе обновления прошивки), при этом отправка данных на сервер будет штатно завершаться.

Если Вы не хотите, чтобы при очередной синхронизации прошивка обновлялась, надо выбрать пустую строчку в пунке меню `Система` -> `Обновление ПО` -> `Обновить до`.

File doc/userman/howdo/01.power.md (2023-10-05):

# Включение и выключение

## Включение питания

Нажатие на среднюю кнопку:

* Если прибор выключен:

    * Удержание менее 5 секунд - отображает заряд батареи.

    * Удержание более 5 секунд - включает прибор.

* Если прибор был в режиме сна:

    * Пробуждает из режима сна.

## Отключение питания

На данный момент одной из основных проблем устройства является потребление энергии от аккумулятора. При этом устройство при полностью активном режиме может разрядиться меньше, чем за один световой день.

Выключение возможно:

* Вручную.

    * Меню: `Система` -> `Выключить питание`.

    * Меню: `Параметры` -> `Автовыключение` -> `Выключить вручную`.
    
* Через заданное количество часов отсутствия взлётов.

    Меню: `Параметры` -> `Автовыключение` -> `Без взлётов`.

    Время указано в часах.

* Через заданное количество часов после включения.

    Меню: `Параметры` -> `Автовыключение` -> `После включения`.

    Время указано в часах.

## Режим сна

В режиме сна прибор потребляет меньше, чем в активном состоянии, но больше, чем в выключенном.
В режиме сна заряда батареи хватает примерно на неделю.

Прибор НЕ уходит в режим сна, если:

* начиная со взлёта выше 40 метров, заканчивая приземлением;

* включена навигация;

* есть подключение по Wi-Fi.

Переход в режим сна не настраивается.

Прибор выходит из режима сна:

* при переходе в режим "взлёт" (начался набор выше 40 метров);

* нажатием на среднюю кнопку.

Прибор уходит в режим сна при бездействии более 20 секунд.

При заводских настройках:

* навигация включается вместе с включением прибора, и это не позволяет прибору уйти в сон;

* после приземления навигация отключается и прибор уходит в сон автоматически.

Управлять автоматическим включением и выключением навигации можно в меню:

`Параметры` -> `Режим навигации`

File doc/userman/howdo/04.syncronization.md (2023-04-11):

# Синхронизация

На данный момент синхронизация устройства с внешним миром доступна только с помощью WiFi.

С этим связано несколько проблем. Например, кнопками управления не получится ввести пароль к WiFi-сети. Поэтому первую синхронизацию получится выполнить только через WiFi-сеть, не защищённую паролем.

В будущих версиях прошивки планируется подключение из приложение к прибору по bluetooth.

## Список WiFi-сетей

Сети могут быть помечены справа символами:

* без пометок - открытая сеть, можно подключаться.
* `x` - эта сеть защищена шифрованием/паролем, подключение невозможно.
* `+` - эта сеть защищена паролем, и пароль к этой сети указан в настройках, можно подключаться.

## Как подключаться к сети с паролем

Пароль с самого устройства ввести нельзя. 

Зато это можно сделать:

* в приложении,

* с помощью Web-аккаунта на сайте [xdeya.cliffa.net](http://xdeya.cliffa.net).

    * Зайдите под своим аккаунтом (если его ещё нет, зарегистрируйте).
    * В самом верху страницы будет пункт: `Пороли для WiFi` и ссылка на изменение списка.
    * Добавляем нужную сеть и указываем к ней пароль.

    После изменения и синхронизации список сетей будет отправлен на устройство.

## Через приложение

Приложение доступно для платформ:

* Windows

* Mac OS

* Android

* iOS

[подробнее...](../../download.md#приложение)

Меню: `Синхронизация` -> `Приложение по WiFi`.

Необходимо выбрать WiFi-сеть, после чего устройство выйдет из меню и продолжит обычну ю работу, а в фоне будет подключаться к WiFi-сети. Если это первое подключение, то только к сети без пароля
(а начиная с версии прошивки `v0.7.5`, можно использовать WiFi-сеть с паролем "по умолчанию": z12344321).

Устройство должно появится в приложении в списке устройств, если компьютер или телефон подключен к той же WiFi-сети.

При подключении в приложении потребуется ввести буквы-цифры, появившиеся на приборе в момент подключения к нему.

## Через аккаунт на сервере

Меню: `Синхронизация` - `На сервер по WiFi`

Необходимо выбрать WiFi-сеть. Если это первое подключение, то только к сети без пароля
(а начиная с версии прошивки `v0.7.5`, можно использовать WiFi-сеть с паролем "по умолчанию": z12344321).

Если не производилась привязка к аккаунту, то на экране отобразятся буквы-цифры, которые необходимо указать на Web-сервере.

Остальной процесс происходит самостоятельно.

На сервер будут отправлены:

* информация о прыжках,
* записанные треки.

С сервера на устройство будет передана информация об указанных паролях для WiFi-сетей.

## Привязка устройства к Web-аккаунту

Если устройство ещё не было привязано к Web-аккаунту, при попытке синхронизировать на экране появится надпись: `Ожидаем привязки`, а посередине экрана будет отображено 4 буквы/цыфры.

Это устройство ожидает привязки к аккаунту на сайте [xdeya.cliffa.net](http://xdeya.cliffa.net).

* Зайдите под своим аккаунтом (если его ещё нет, зарегистрируйте).
* Справа в верхнем углу будет значёк шестерёнки. При клике на неё выпадет меню действий.
* Выберите `Привязать устройство`.
* В открывшейся форме надо ввести те самые 4 буквы/цыфры и нажать кнопку `Привязать`.

После этого устройство будет привязано к этому аккаунту, и синхронизация продолжится.

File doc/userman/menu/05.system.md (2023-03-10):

# Система

В этом разделе расположены служебные функции по обслуживанию устройства.

## Выключить вручную

`Длинным нажатием` на `среднюю кнопку` выключает питание устройства.

На деле же, устройство не отключается от источника питания (аккумулятора). Центральный процессор переходит в `режим глубокого сна`, дисплей переходит в режим энергосбережения, микроконтроллер NAVI отключается от питания полностью, а барометр остаётся подключенным к источнику питания - его энергопотребление минимально.

Работа центрального процессора ограничивается слежением за нажатием на кнопки, чтобы включить устройство обратно.

Обратно устройство включается `Длинным нажатием` на `среднюю кнопку`.

## Перезагрузить

`Длинным нажатием` на `среднюю кнопку` перезагружает устройство.

Функция нужна только при нештатной работе устройства.

## Сброс всех настроек

`Длинным нажатием` на `среднюю кнопку` сбрасывает все настройки устройства, в т.ч. отвязывает от Web-аккаунта.

## Обновление прошивки

Сам процесс обновления прошивки будет происходить во время синхронизации. В этом разделе можно выбрать версию прошивки, на которую обновляться.

Пункты меню:

* Текущая версия прошивки.
* Тип текущей прошивки.
* Аппаратная версия.
* Выбор прошивки, на которую обновляться.
* Обновление с SD-карты.

Типы прошивки:

* prod - обычная пользовательская прошивка
* debug - как и обычная, но включен режим отладки, в консоль отправляется служебная информация
* dev - прошивка разработчика, при синхронизации используется другой сервер, специально для отладки при разработке

Для каждой версии прошивки можно выбрать язык сообщений на дисплее: `русский` и `английский`.

Обновление прошивки при синхронизации будет происходить только если выбрана версия прошивки в пункте `Выбор прошивки`.

Обновление с SD карты доступно для аппаратной `[v.0.5]` и ПО `v0.6.3`. В этом подразделе нужно выбрать файл прошивки.
При наличии звёздочки (*) перед именем говорит о наличии MD5-файла, который поможет проверить целостность файла прошивки.
Отсутствие этого файла принципиально ни на что не влияет.

## Файлы

Все настройки устройства, логбук и записанные треки хранятся в виде файлов на внутренней `flash-памяти`.

В данном разделе можно посмотреть, какие файлы есть во внутренней памяти, и управлять ими:

* удаление файла - `длинным нажатием` на `среднюю кнопку`
* перенумерование логбук-файлов
* перенумерование треков

Треки и логбук хранятся в файлах, которые нумеруются по порядку. Если какой-то из этих файлов будет удалён, необходимо перенумеровать весь список. Иначе логбук или треки будут некорректно работать.

## Модуль навигации

Спец-операции с чипом навигации:

* Включение режима NAV-serial позволяет управлять микропроцессором NAV-приёмника через серийный порт устройства.

* Список всех спутников, сигнал от которых видит NAV-приёмник.

        [02 GPS ] q-1   (17/60)
        [1d GPS ] q-7   (74/95)    30 dB
        [ff GLON] q-7   (74/95)    20 db

    * В квадратных скобках указан идентификатор спутника - числовой svId и тип.

    * `q-N` - качество сигнала, где N:

        * 0 - нет сигнала
        * 1 - поиск сигнала
        * 2 - сигнал получен
        * 3 - сигнал определён, но его нельзя использовать
        * 4 - код заблокирован, часы синхронизированы
        * 5-7 - код и сигнал заблокированы, часы синхронизированы

    * Если после `q-N` отображается `*`, значит этот спутник используется для навигации

    * В круглых скобках: возвышение (-90..+90) и азимут (0..360)

    * Справа - отношение сигнал/шум

* Отображение версии прошивки чипа навигации.

* Холодный перезапуск NAV-приёмника, при котором будет сброшен список спутников.

## Тестирование аппаратуры

Этот раздел позволяет проверить протестировать корректность работы узлов устройства.

* Часы - Даже если не синхронизированы, время должно идти, а не стоять на месте.
* Напряжение на батарее - Показывет текущее рассчитанное напряжение, должно быть в пределах `3.0-4.2 Вольт`.
* Заряжается ли батарея - При подключении USB-зарядки должно отображать `Да`.
* Показания барометра - Текущее атмосферное давление, должно быть в пределах `9-11 кПа`.
* Подсветка экрана - Включает подсветку по длинному нажатию на `среднюю кнопку` и через секунду подсветка отключается.
* Компас - Если включен опционально и поддерживается аппаратно.
* Данные с NAV-приёмника - Показывает задержку в приёме данных, она не должна превышать `500 мс`.
* Перезапуск по питанию микропроцессора NAV-приёмника -  По `длинному нажатию` на `среднюю кнопку`.
* Повторная инициализация NAV-приёмника - требуется, если NAV-приёмник был перезапущен пунктом выше.

## Калибровка магнетометра

Ручная калибровка компаса.

Подробно эта процедура описана в разделе [Как сделать / Навигация](../howdo/01.navigation.md#как-откалибровать-компас)

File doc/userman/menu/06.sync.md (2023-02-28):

# Сохронизация

Подробнее о процессе синхронизации рассказано в разделе [Как сделать / Синхронизация](../howdo/03.syncronization.md)

## Приложение по WiFi

Включение возможности подключиться из приложения к прибору через WiFi-сеть.

Мобильному устройству или компьютеру, на котором запускается приложение, должны быть подключены
к той же WiFi-сети, что и прибор.

Если выбор сети ещё не осуществлялся, то он будет предложен.

Если подключение к wifi-сети уже выполнено, то мы попадём в подменю, где можно:

* Увидеть, какая сеть выбрана.
* Есть ли подключение к этой сети.
* Выполнено ли подключение из приложения.
* Остановить WiFi-процесс.

## На сервер по WiFi

Устаревшая синхнонизация с аккаунтом на сервере.

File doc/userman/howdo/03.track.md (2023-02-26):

# Трек

## Как записать трек

* Вручную

    * При заводских настройках нижней кнопкой: `длинное нажатие`

        Изменить в меню: `Параметры` -> `Функции кнопок`

    * Меню: `Параметры` -> `Трек` -> `Писать сейчас` - длинное нажатие.

* Автоматически

    * При отделении от ЛА (выключится на приземлении)

        Это поведение нельзя изменить

    * На заданной высоте в подъёме

        Изменить в меню: `Параметры` -> `Трек` -> `Запись на высоте`

## Куда записывается трек

* Если нет SD-карты, то на внутреннюю память

    * Внутренняя память ограничена несколькими мегабайтами

    * Свободное место в меню: `Параметры` -> `Трек` -> `Доступно для записи`

        Время указано в `мин`:`сек`.

        Тут же указано количество сохранённых во внутреннюю память треков.

    * Если при записи место будет заканчиваться, будет удалён самый старый трек.

    * Если все треки кроме текущего были удалены, а запись продолжается и место закончилось,
        запись будет остановлена.

* Если есть SD-карта, то трек будет записан на нёё.

    * Свободное место на SD-карте никак не проверяется и его нельзя посмотреть прибором.

    * Максимально будет записано только 99 треков, самые старые будут стираться. В будущих прошивках это ограничение будет снято.

## Как посмотреть трек

* Через приложение:

    * либо при просмотре информации о прыжке,

    * либо в общем списке всех треков на устройстве.

* Через аккаунт на сервере.

Оба способа описаны в разделе [Синхронизация](03.syncronization.md)

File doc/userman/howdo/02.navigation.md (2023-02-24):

# Навигация

## Как включить или отключить Компас

Меню: `Параметры` -> `Использовать Компас`

* При подключенном аппаратном компасе - отображения сторон света на экране соответствует показаниям компаса.
        
* При отсутствии компаса - север всегда сверху

## Куда показывает стрелка

Направление нашего движения отображается как на карте, где мы в центре "карты". Самой карты нет, но вы понимаем, куда мы движемся относительно сторон света и где находится точка.

Начиная с версии `v0.5.3` отображения сторон света на экране соответствует показаниям компаса, если таковой есть. Т.е. при наличии компаса "карта" будет вращаться. При отсутствии компаса - север всегда будет вверху дисплея.

**Важно** помнить, принципиально - направление нашего движения, а не куда мы смотрим. Мы можем двигаться спиной вперёд.    

## Как менять отображение навигации на экране

* Два варианта отображения:
    
    * Страница "навигация + высотомер"
    
    * Страница "навигация" - тут тоже есть отображение высоты, но основное внимание навигации.

На земле меняется средней кнопкой.

После прыжка по умолчанию переходит на страницу "навигация + высотомер".

Изменить в меню: `Параметры` -> `Автоперекл. экрана` -> `После раскрытия`

## Как откалибровать компас

Т.к. производство китайских деталей не отличается стабильностью, показания, снимаемые магнитометром от экземпляра к экземпляру сильно расходятся.

Если компас показывает нестабильно направление севера, это значит, что магнетометр необходимо калибровать. Эта функция находится в меню `Система` - `Калибровка магнетометра`.



Суть калибровки заключается в нахождении минимальных и максимальных значений магнетометра. Для этого каждую из осей (X, Y, Z) необходимо направлять вдоль магнитных линий Земли.

> На широте Москвы магнитные линии направлены примерно под углом 60° к поверхности.

Для каждой оси прибора необходимо сделать две манипуляции - в прямом направлении магнитной линии и в обратном. Каждый раз будет определяться либо минимум,
либо максимум по выбранной оси. Минимум и максимум определяем незначительными отклонениями вдоль предполагаемой оси.

Для сохранения результатов - длинное нажатие средней кнопкой.

Для выхода из калибровки - короткое нажатие на среднюю кнопку.

## Питание GPS/GLONASS-приёмника

Управление питанием GPS/GLONASS-приёмника актуально для экономии заряда батареи.

По умолчанию, при включении устройства включается и приёмник.

Управлять питанием приёмника можно через меню `Параметры` -> `Управление режимом питания NAV-приёмника`.

Среди возможностей настройки:

* Ручное управление.
* Включение питания при включении устройства.
* Включение питания при записи трека.
* Включение питания на заданной высоте.
* Безусловное выключение при приземлении.

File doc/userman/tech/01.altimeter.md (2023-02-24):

# Высотомер

Как и во всех других высотомерах, для определения текущей высоты применяется датчик давления.

## Подстройка уровня "Земли"

При включении устройства текущее атмосферное давление принимается за давление `нулевой высоты`.

Пока высотомер находится в режиме `На земле`, каждые 10 минут производится подстройка `нулевой высоты` до текущего давления.

Если высотомер будет в любом другом режиме, автоподстройка производиться не будет. Автоподстройку ещё можно отключить через меню `Параметры` -> `Подстройка уровня земли`.

Из режима `На земле` высотомер выйдет, если скорость подъёма будет выше `1.5 м/с` или высота будет выше `50 м`.

## Сложности вычисления высоты по барометру

Основной проблемой для любых приборов, измеряющих высоту по барометру, являются зоны турбулентности и зоны повышенного давления. Особенно заметно это проявляется на скоростях `более 20 м/с` в любом направлении.

**Зоны турбулентности** встречаются достаточно часто:

* В летательном аппарате - это обычно зона у открытой двери.
* В свободном падении существенно турбулентный поток возникает над рукой, на которой закреплён высотомер.

**Зона повышенного давления** формируется в двух случаях:
* если измеряющее давление устройство находится под телом в непосредственной близости от него в свободном падении;
* в салоне самолёта, если размеры двери небольшие по сравнению с объёмом салона.

Например, в инструкциях ко многим страхующим приборам в явном виде это описано. И указывается, что в положении на животе (когда прибор находится в зоне пониженного давления на спине) прибор сработает на `80 метров` ниже, чем в положении на спине (когда прибор находится в зоне повышенного давления).

В некоторых случаях погрешность показаний может достигать `более ±100 метров`. Помните об этом при учёте показаний с подобных приборов, в т.ч. и этого.

Вот пример замера высоты в момент отделения с ЛА с боковой дверью. Поля: время в мс, высота по барометру и высота по GPS/GLONASS (над уровнем моря). Частота замеров - 10 раз в секунду, однако, данные с NAV-приёмника идут 5 раз в секунду.

    3294		3991		4288
    3396		3989		4287
    3494		3993		4287
    3596		3989		4285
    3694		3987		4285
    3796		3994		4283
    3894		4010		4283
    3996		4002		4282    <-- Примерно тут высотник оказался за обрезом
    4093		4025		4282
    4197		4009		4279
    4293		4044		4279
    4395		4056		4277
    4493		4064		4277
    4595		4063		4274
    4692		4072		4274
    4794		4035		4272
    4892		4071		4272
    4994		4085		4268
    5092		4107		4268
    5196		4100		4265    <-- Примерно тут уже началось падение
    5292		4087		4265
    5394		4075		4261
    5492		4065		4261
    5594		4044		4257
    5691		4027		4257
    5793		4013		4253
    5890		4006		4253
    5992		4011		4249
    6090		4023		4249
    6194		4009		4243
    6290		4014		4243
    6392		4010		4238
    6489		3996		4238
    6591		4022		4232
    6688		4015		4232
    6790		4019		4226
    6888		4000		4226
    6990		4009		4220
    7087		4050		4220
    7191		4050		4214
    7287		4048		4214
    7389		4039		4207
    7486		4021		4207

Далее показания высоты уменьшались более последовательно.

График замеров текущей высоты

Приведён пример отделения горизонтальной 8-way в захватах из самолёта Л-410. Устройство было на руке участника, отделяющегося из салона. А отделение мы завалили :smile:. Если устройство повесить на руку, отделяющегося снаружи, там всё ещё веселее.

Всё это создаёт значительные трудности в определении момента отделения. У высотомеров более известных брендов трудности те же самые, именно поэтому не стоит сильно доверять показаниям в вашем логбуке.

Напрашивается сразу же предложение - ориентироваться на GPS/GLONASS. Но обычно на отделении, особенно пока вывешиваемся и берём друг друга за захваты, в этот момент сигнал теряется и возобновляется только через какое-то время после отделения.

## Алгоритм определения фаз прыжка

В отличие от более простых высотомеров, где не так критична точность определения начала прыжка, в этом устройстве при начале прыжка требуется засечь текущие координаты и включить запись трека. Если точность определения прыжка будет низкой, полезность данного устройства будет сомнительной.

1. Каждый прыжок должен начинаться с подъёма. Эта фаза включается, когда примерно 5 секунд продолжается набор высоты. Без этой фазы все остальные невозможны.

2. Снижение может возникать по многим причинам:
    - удержание полёта на одном эшелоне,
    - временное снижение ЛА,
    - снижение некоторых ЛА при сбросе газа `на боевом`,
    - резкие изменения давления.
    
    Поэтому для однозначного определения, что это именно отделение, скорость снижения дожна быть не менее 15 м/с на протяжении 5 секунд. В этом случае принимается решение, что это всё-таки отделение и падение.
    
    Моментом отделения считается тот, что был 5 сек назад на момент принятия решения. Опыты показали, что это максимально близко к правде, если отделяться изнутри салона. Если сначала вывешиваться за бортом, то ошибка определения момента отделения достигает 2 сек.

3. Теперь надо решить, открыли ли мы парашют под бортом или падаем в свободном падении. Если за последующие 3 секунды скорость снижения достигнет 35 м/с, считается, что прыжок начался со свободного падения. Иначе, в логбук будет записано нулевое время свободного падения.

4. Если у нас всё-таки случилась фаза свободного падения, то она завершится, если около 6 секунд скорость снижения будет ниже 12 м/с. Моментом открытия будет тот, что был 6 секунд назад перед принятием решения.

5. Момент приземления - если высота ниже 50 метров сохраняется более 6 секунд.

Для того, чтобы в логбук писать верные значения, т.к. определение моментов начала каждой фазы происходит с опозданием в несколько секунд, ведётся непрерывный лог параметров на протяжении прошедших 10 секунд. И после принятия решения для каждой фазы нетрудно получить параметры начала фазы.

Этот алгоритм показал стабильный и достаточно точный результат. Однако, иногда фаза свободного падения не засчитывается.

Иногда на выброске ЛА длительное время достаточно интенсивно снижается. Обычно пилоты намеренно начинают снижение на выброске, чтобы не допустить свала. Однако, это может привести к ошибочному принятию решения о моменте начала прыжка.

При достаточно большой статистике, подтверждённой средствами объективного контроля, получится доработать алгоритм для получения более точных показаний. Для этого достаточно присылать трек прыжка вместе с видео этого прыжка разработчикам с пометкой: `для доработки алгоритма определения прыжка`.

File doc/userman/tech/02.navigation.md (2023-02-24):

# Навигация

Приём GPS/GLONASS-сигнала происходит на активную патч-радиоантенну внутри пластикового корпуса устройства.

Далее сигнал приходит в микрочип u-blox m8n. Этот чип умеет принимать одновременно сигналы GPS и GLONASS.

## Качество принимаемого сигнала

К сожалению, качество принимаемого сигнала - одна из основных решаемых сейчас проблем. Обшивка большинства летательных аппаратов очень хорошо экранирует любые радиосигналы, в т.ч. - GPS/GLONASS.

В городе на улице приём средне-уверенный.

В квартире - спутники можно поймать только у окна.

На аэродроме на улице обычно нет проблем с приёмом сигнала. Количество принимаемых спутников обычно не ниже 16.

## Внутри летательного аппарата

* v.0.3 - экран небольшой, антенна расположена так, чтобы её ничто не закрывало, кроме пластика корпуса.
* v.0.4 - экран намеренно увеличен почти на всю площадь, но ради этого пришлось пожертвовать открытой площадью антенны - она почти полностью закрыта, это весьма пагубно повлияло на уровень  принимаемого сигнала.
* v.0.5 - экран такой же, как в `v.0.4`, но площадь антенны так же, как в `v.0.3` полностью вынесена из-под экрана для максимально хорошего приёма.

Статистика приёма внутри разных ЛА:

| | v.0.3 | v.0.4 |
|:---:|:---:|:---:|
| Ан-2 | У кабины - неплохо, у двери (даже открытой) часто пропадает. | Плохой приём, к моменту отделения спутники всегда надёжно терялись. |
| Ан-28 | У кабины ловит плохо, у рампы до 3000м хорошо, выше - только у окна. | Плохой приём, к моменту отделения спутники всегда надёжно терялись. |
| Л-410 | На удивление - хороший устойчивый сигна везде, иногда может потребоваться поднести к окну. | Неустойчивый приём, часто приходится подносить к окну. |
| Ми-9 с открытой рампой | Хороший устойчивый приём, иногда лучше подносить к окну или на максимальное расстояние от любого человека. | - нет статистики - |

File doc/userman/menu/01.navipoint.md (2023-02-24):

# NAVI-точки

Здесь настраивается до трёх точек с координатами. Направление и расстояние до любой выбранной из них можно будет видеть на главном экране.

## Выбранная точка

Выбрать можно только одну точку. Каждая точка обозначена номером (`1`, `2`, `3`).

Если рядом с номером точки присутствует `(нет)`, значит для этой точки ещё не сохранены координаты (свободная для использования ячейка).

Вариант `[без точки]` отключает отображение стрелки и расстояния до точки на главном экране.

## Сохранить координаты

Для выбранной точки можно сохранить координаты текущего местоположения. Для этого надо удерживать 4 секунды среднюю кнопку на одноимённом пункте меню в том географическом положении, которое мы хотим сохранить.

Возможные ошибки:

* Точка не выбрана - в качестве выбранной точки: "[без точки]".
* Нет NAVI спутников - потеряна связь до спутников (об этом подробнее - ниже).
* Ошибка сохранения - проблемы с внутренней flash-памятью.

Несмотря на то, что NAV-антенна находится с противоположной стороны от кнопок управления, тем не менее, на практике замечено, что при длительном нахождении пальцев в области кнопок связь до спутников может потеряться. Это актуально и для исполнения [v.0.3](https://github.com/cliffanet/xdeya-altimeter/blob/master/doc/models/01.v.0.3.md), и для исполнения [v.0.4](https://github.com/cliffanet/xdeya-altimeter/blob/master/doc/models/02.v.0.4.md).

Если потеря связи произошла, пока мы лазили по меню и пытались сохранить точку - увидев сообщение `Нет NAV спутников`, обычно достаточно на 5-8 секунд убрать пальцы от высотника и попробовать ещё раз сохранить координаты.

## Очистить точку

У выбранной точки очищаются координаты, и она становится свободным слотом.

Для сохранения координат для выбранной точки необязательно её перед этим очищать. Однако, это добавит `(нет)` к номеру точки в пункте [Сохранить координаты](#сохранить-координаты), и в будущем будет легче выбрать точку, чтобы не затереть какие-то важные координаты.

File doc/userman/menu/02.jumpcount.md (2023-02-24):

# Количество прыжков

Стандартный пункт для любого высотомера. Необходим для удобства ведения записи прыжков.

Количество прыжков автоматически увеличивается через 5 секунд после отделения от ЛА (Летательного Аппарата).

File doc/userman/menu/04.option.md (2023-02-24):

# Параметры

В этом разделе можно произвести настройку устройства под свои нужды.

## Дисплей

* Подсветка - ручное включение подсветки дисплея.
* Контраст - корректировка чёткости отображения.
* Развернуть на 180 - для ношения на правой руке антенной со стороны кисти.

## Подстройка уровня земли

* Сбросить `уровень земли` вручную - примет текущее давление за `уровень земли`.
* Разрешение ручного сброса.
* Автоподстройка - вкл/выкл автоматической подстройки `уровня земли`.
* Превышение площадки приземления относительно уровня взлёта.

## Автопереключение главного экрана

Главный экран можно автоматически переключать на определённую страницу при некоторых событиях:

* Свободное падение - тут выбор только `да` или `нет`, при выборе `да` экран переключается в режим высотомера и отключает кнопки управления, пока скорость эквивалентна скорости свободного падения.
* После раскрытия
* При приземлении
* При длительном нахождении на земле
* При включении устройства

У всех пунктов, кроме первого, актуальны варианты:

* Страница `NAV + Высотомер`.
* Страница `Высотомер`.
* Предыдущая страница - та, что была выбрана до момента отделения от ЛА.
* Не менять - ничего не менять при данном событии.

## Автовыключение

Устройство можно автоматически выключить при следующих событиях:

* Выключить вручную - `длинное нажатие` на `среднюю кнопку`.
* Без взлётов - если с предыдущего взлёта (с момента приземления или включения устройства) прошло выбранное количество часов.
* После включения устройства прошло выбранное количество часов.

## Управление режимом питания NAV-приёмника

Энергопотребление NAV-приёмника весьма существенное. При его постоянно включенном состоянии полного заряда аккумулятора может не хватить даже на один световой день.

* Текущее состояние - `включение` и `выключение` питания приёмника вручную.
* Включение питания при включении устройства - `да` / `нет`.
* Включение питания при записи трека - `да` / `нет` (будет автоматически выключено при остановке записи трека).
* Включение питания на высоте - можно выбрать высоту, на которой приёмник включится автоматически (и автоматически выключится при приземлении).
* Выключать при приземлении - `да` / `нет` - независимо от настроек выше, после приземления в любом случае будет выключено.

После включения питания во всех случаях NAV-приёмник будет проинициализирован, настроен. Однако, на приём сигналов от спутников требуется некоторое время, особенно, если приёмник был с отключенным питанием длительное время.

Помимо этого тут можно выбрать типы спутников: GLONASS, GPS, GLONASS+GPS.

## Включение аппаратного компаса

На данный момент реализация аппаратного компаса доступна:

* в версии `v.0.5` и выше
* в более старых аппаратных версиях с заказом допопций

Но во всех случаях аппаратный датчик работает пока неочень хорошо, поэтому по умолчанию он отключен.

## Курс текстом

Отобразит на странице "Только навигация" курс движения и курс до точки числом в градусах.

## Функции кнопок на главных экранах

На главных экранах функциями кнопок `Вверх` и `Вниз` по `длинному нажатию` на них можно управлять:

* не исп. - отключить кнопку на главных экранах.
* Подсветка -  `вкл` / `выкл`.
* Питание NAV-приёмника -  `вкл` / `выкл`.
* Запись трека - `вкл` / `выкл`.
* Выключить питание устройства.

## Работа с треками

* Писать сейчас - отображает текущий режим записи трека. `Длинным нажатием` можно `включить` или `выключить` запись.
* Автозапись на высоте - можно выбрать высоту в подъёме, при которой запись трека включится автоматически.
* Текущее количество треков.
* Доступно для записи треков - в минутах и секундах.

При записи трека, если свободного места остаётся мало, автоматически удаляются более старые треки. Если остаётся только тот трек, который записывается в настоящее время, все остальные треки были уже удалены, а место всё равно заканчивается, запись трека будет остановлена.

**Важно:** В момент отделения от ЛА запись трека всегда начинается автоматически.

Если запись трека была изначально выключена и включилась автоматически в момент отделения от ЛА, в этом случае она автоматически выключится после приземления.

## Настройка часов

Тут выбирается часовой пояс по `UTC` с интервалом в 30 минут.

При доступности GPS/GLONASS-спутников часы всегда синхронизируются по ним.

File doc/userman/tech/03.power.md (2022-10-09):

# Режимы питания

Различные режимы питания нужны для максимально эффективного сбережения энергии батареи питания, насколько это возможно.

Все переключения из режима в режим происходят автоматически, управлять этим нельзя.

## Активный режим

В этом режиме устройство не прерывает свою работу для обеспечения стабильности в тех процессах, из-за которых этот режим сохраняется.

Причины, по которым устройство переходит в `активный` режим:

* Высотомер вне режима `На земле`.
* Включено питание NAV-приёмника.
* Происходит WiFi-синхронизация.

Это обусловлено работой шин связи центрального процессора.

## Пассивный режим

Если отсутствуют все причины перехода в `активный` режим, устройство переходит в `пассивный`.

В этом режиме центральный процессор переходит в сон 10 раз в секунду на всё свободное от работы время. Обычно это - более 80% времени.

## Спящий режим

Если в `пассивном` режиме не трогать кнопки управления более 20 секунд, устройство переходит в `спящий` режим.

В этом режиме центральный процессор переходит в более глубокий сон, чем в `Пассивном` режиме, на 5 секунд. И просыпается только, чтобы измерить текущее атмосферное давление.

Если за несколько таких просыпаний обнаруживается, что начался подъём на высоту, устройство переходит в `активный` режим.

При этом режиме гаснет дисплей и отключаются кнопки управления. Перейти обратно в `Пассивный` режим можно `средней кнопкой`. К сожалению, архитектура выбранной схемы и микропроцессора не позволяют выходить из спящего режима любой кнопкой.

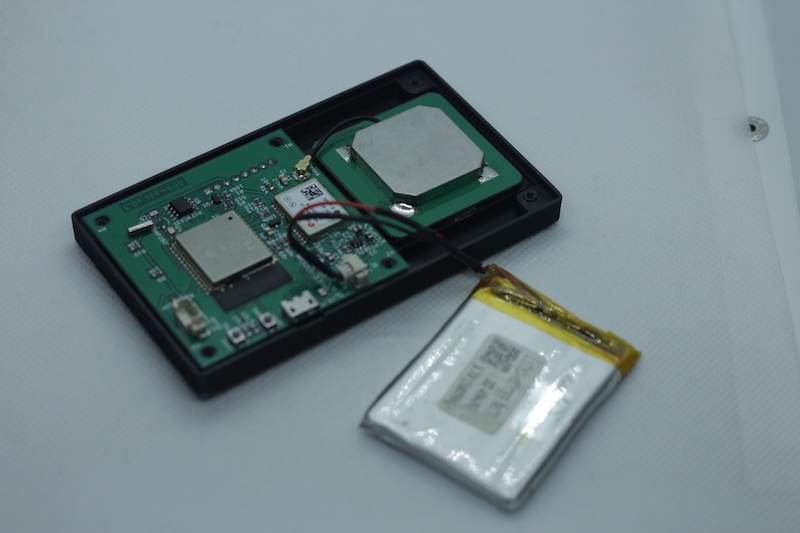
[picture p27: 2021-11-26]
doc/models/img/v0.3.i.01.jpg

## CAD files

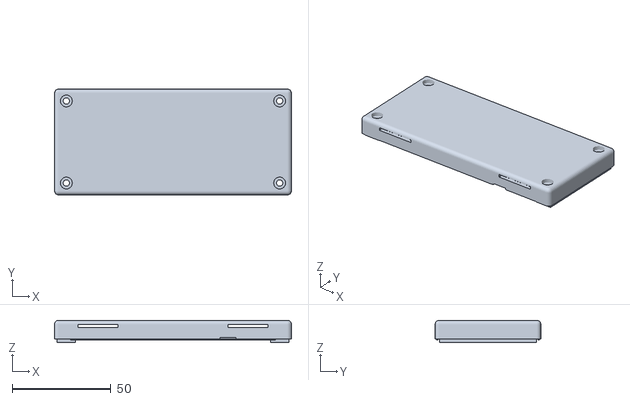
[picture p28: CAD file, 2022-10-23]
box/xdeya-box-int-bottom-lent.stl
119.9 x 53.5 x 11.3

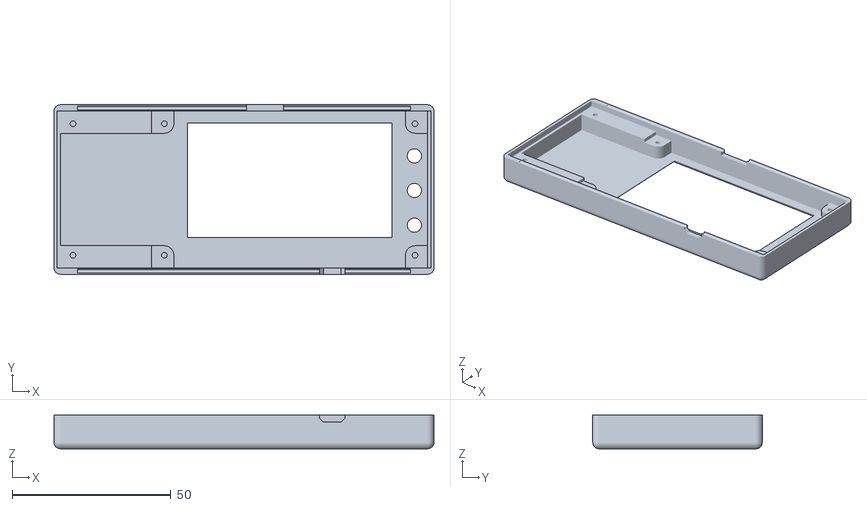
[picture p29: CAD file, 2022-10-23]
box/xdeya-box-int-top.stl
119.9 x 53.5 x 10.6

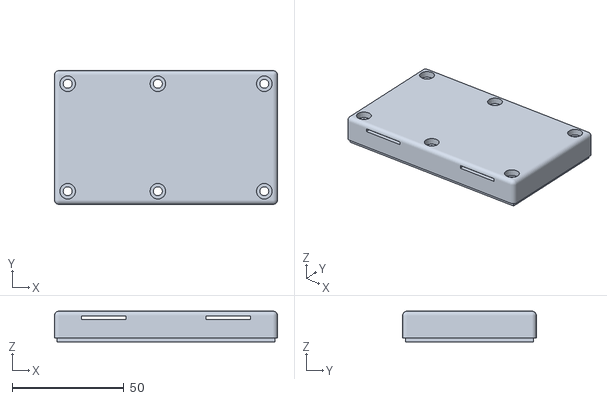
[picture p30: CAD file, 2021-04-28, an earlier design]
arch.hw/v0.3/box/xdeya-box.v0.3-bottom.stl
100.0 x 60.0 x 13.8

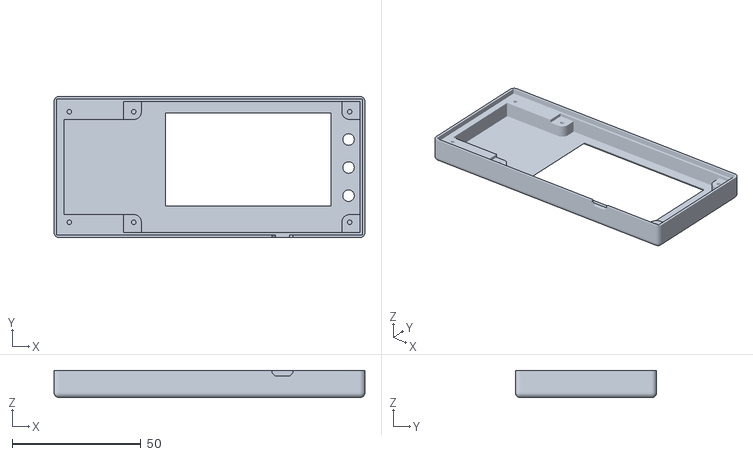
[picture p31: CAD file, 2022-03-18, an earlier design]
arch.hw/v0.4.1/box/xdeya-box.v0.4.1-long-top.stl
121.0 x 55.0 x 10.6

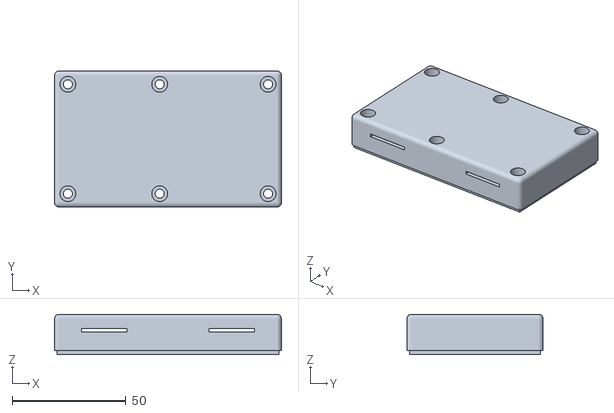
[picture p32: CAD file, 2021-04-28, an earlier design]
arch.hw/v0.3/box/xdeya-box.v0.3-bottom-bold.stl
100.0 x 60.0 x 17.8

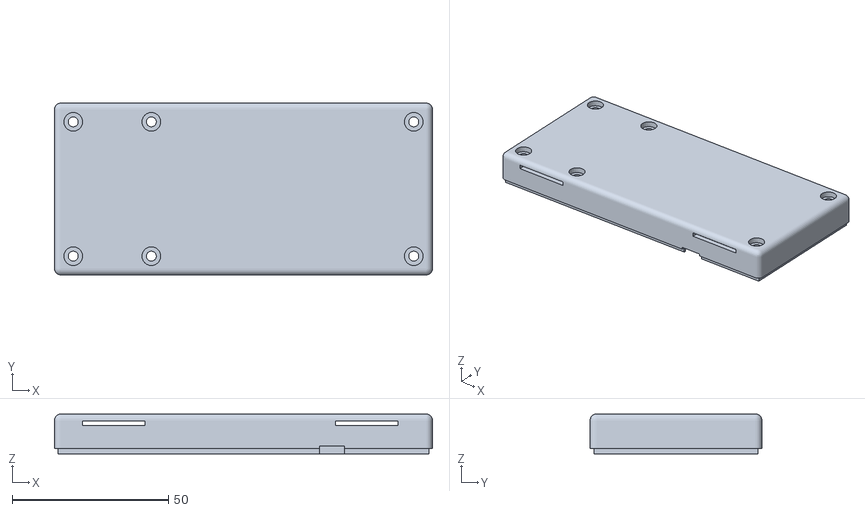
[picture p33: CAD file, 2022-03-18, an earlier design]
arch.hw/v0.4.1/box/xdeya-box.v0.4.1-long-bottom-lent.stl
121.0 x 55.0 x 12.8

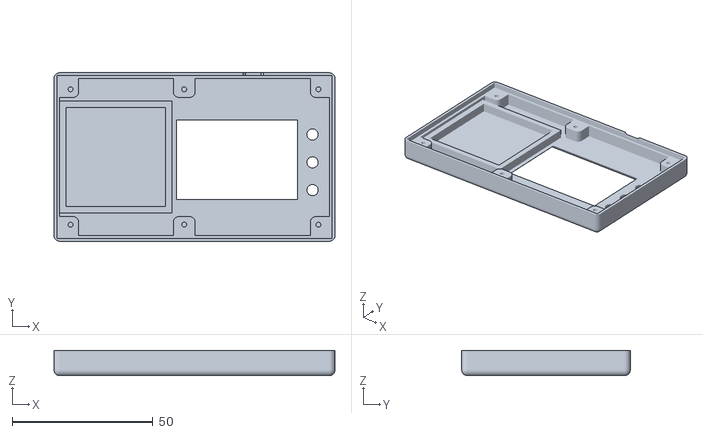
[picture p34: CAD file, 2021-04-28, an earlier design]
arch.hw/v0.3/box/xdeya-box.v0.3-top.stl
100.0 x 60.0 x 9.00

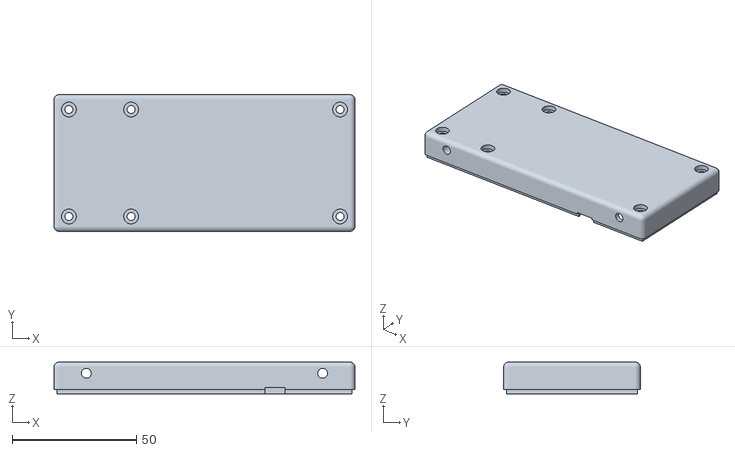
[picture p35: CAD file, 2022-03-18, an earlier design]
arch.hw/v0.4.1/box/xdeya-box.v0.4.1-long-bottom-cord.stl
121.0 x 55.0 x 12.8

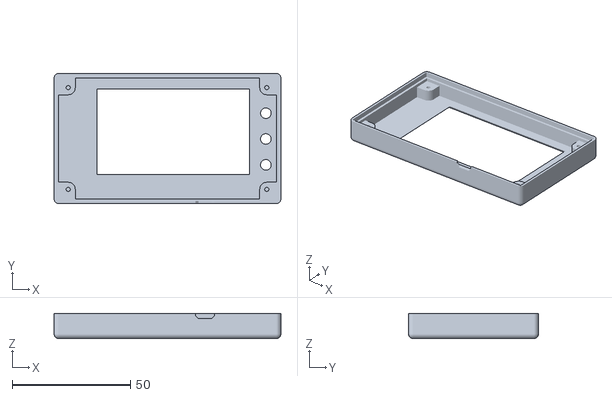
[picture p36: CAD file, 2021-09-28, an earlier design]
arch.hw/v0.4.1/box/xdeya-box.v0.4.1-top.stl
96.0 x 55.0 x 10.6

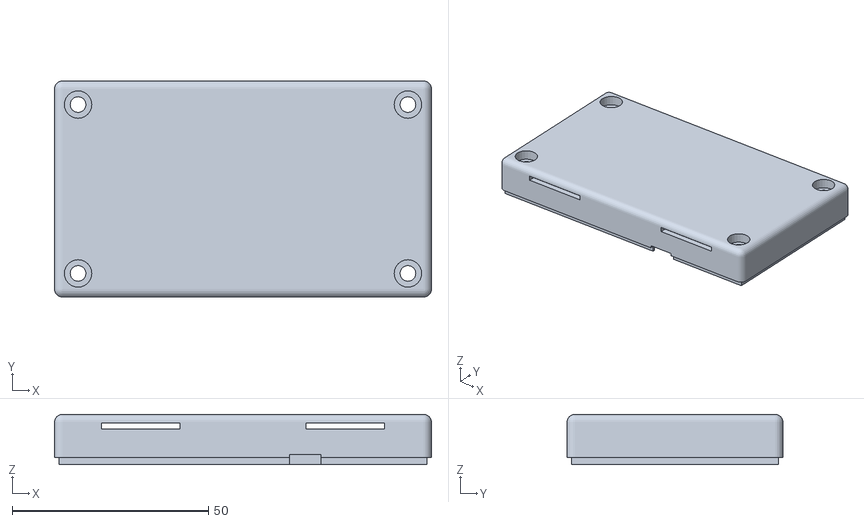
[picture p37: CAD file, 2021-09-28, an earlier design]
arch.hw/v0.4.1/box/xdeya-box.v0.4.1-bottom-lent.stl
96.0 x 55.0 x 12.8

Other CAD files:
box/xdeya-box-int-bottom-cord.stl
arch.hw/v0.4.1/box/xdeya-box.v0.4.1-bottom-cord.stl
arch.hw/v0.3/box/xdeya.skp
arch.hw/v0.4.1/box/xdeya-long-noroundcorner.skp
arch.hw/v0.4.1/box/xdeya-long.skp
arch.hw/v0.4.1/box/xdeya-noroundcorner.skp
arch.hw/v0.4.1/box/xdeya.skp
box/xdeya-ext-noroundcorner.skp
box/xdeya-int-noroundcorner.skp
box/xdeya-int.skp

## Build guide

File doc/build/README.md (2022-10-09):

# Хде-Йа - Аналитика

Меня часто спрашивают, зачем это устройство, оно же большое, используется не самый энергоэффективный чип.

Да, у этого устройства много проблем, сложностей. Однако, мне сильно не хватало навигатора для нужд контроля своей позиции под парашютом. При этом я хотел совместить в нём ряд удобств, которых мне всегда не хватало в дорогих высотниках от крупных известных брендов.

Сейчас я нахожусь на рубеже принятия решения, что дальше делать с этим проектом:

* Если он окажется интересным для пользователей при всех его текущих проблемах, это будет мотивировать меня к дальнейшей разработке и устранению проблем.
* Среди парашютистов я встречал довольно много инженеров, которые пытались и пытаются изготавливать какие-то свои устройства (высотники, пищалки и т.п.) для нашей деятельности. Может для них этот проект поможет этим людям в их разработках.
* Может, кто-то захочет присоединиться к этому проекту. Я открыт для взаимодействия и не планирую оставлять только единоличное право на его ведение.
* Может кто-то из инструкторов подкинет какие-либо идеи, как это можно использовать в обучении.

Однако, если окажется, что проект, кроме меня, больше никому не интересен, скорее всего, на этом его развитие остановится, а я направлю свои силы в другие идеи.

## Текущие возможности и Области применения

Основные аргументы, побудившие к реализации данного проекта:

* Дороговизна современных GPS/GLONASS-решений в качестве возвращалки.
* Желание синхронизировать логбук с внешним миром, задолбался руками вести учёт прыжков.
* Желание иметь потенциальную возможность допрограммировать устройство.

Все остальные фишки - уже скорее следствие.

* Можно использовать для купольного пилотирования (разбор точности при заходе на приземлении и режимов работы купола).
* Можно доработать какую-то свою функцию в готовое железо и использовать её.
* Мне пригождалось в качестве комфортного контроля точки выброски.
* Можно проконтролировать свои навыки ориентирования на местности с высоты (точность определения нахождения точки относительно себя самого).

## Проблемы

### 1. Уровень приёма внутри ЛА

>Ищу способы решения, нужна помощь знающих радиолюбителей.

### 2. Энергосбережение

>Половину ёмкости аккумулятора отъёдает микропроцессор приёма GPS/GLONASS-сигнала. Если его отключать, когда он не нужен, это позволит существенно продлить время работы до ближайшей зарядки.
>
>Схема и чип выбраны тоже не самые эффективные.

### 3. Стабильность распознавания начала свободного падения

>Начало прыжка чаще всего определяется с точностью до 2-3 секунд. Но вот не всегда принимается верное решение, было ли свободное падение или это раскрытие под бортом.
>
>Выражается проблема в нулевом времени свободного падения.
>
>Тут пока нет достаточной статистики. В этом может помочь каждый - присылайте свои треки прыжков. А если приложете ещё и видео прыжка - это тоже сильно поможет.

### 4. Объём места для треков

>Внутри применённого чипа встроена довольно большая flash-память. Однако, её недостаточно, чтобы хранить треки более, чем для 3-6 прыжков. При достаточной заинтересованности проектом - дальнейшее развитие предполагает использование внешней SD-карты.
>
>Возможно, было ошибкой, рассчитывать на внутреннюю память без использования SD-карты с самого начала. Но так проект проще, компактнее и при этом имеет рабочую форму.

### 5. Подвисания при автоматическом старте трека

>Примерно через 5-8 секунд после отделения от ЛА (в момент принятия решения, что начался прыжок) устройство подвисает и не реагирует ни на что несколько секунд.
>
>Происходит это из-за старта записи трека. Именно в начале прыжка на flash-память пишется трек за прошедшие 10 секунд, чтобы прыжок записался с самого начала. Именно это приводит к подвисанию.
>
>Это известная проблема, не решённая пока что программным образом. Скорее всего, со временем проблема будет решена, а пока что её надо иметь ввиду.
>
>Костыльно сейчас её можно решить выставлением в настройках высоты, на которой запись трека будет стартовать автоматически ещё в подъёме. Это удлинит объём записываемого за один прыжок трека (меньше треков влезет), но это позволит включить трек до начала прыжка и автоматически выключить при приземлении. При этом подвисаний при начале прыжка уже не будет.

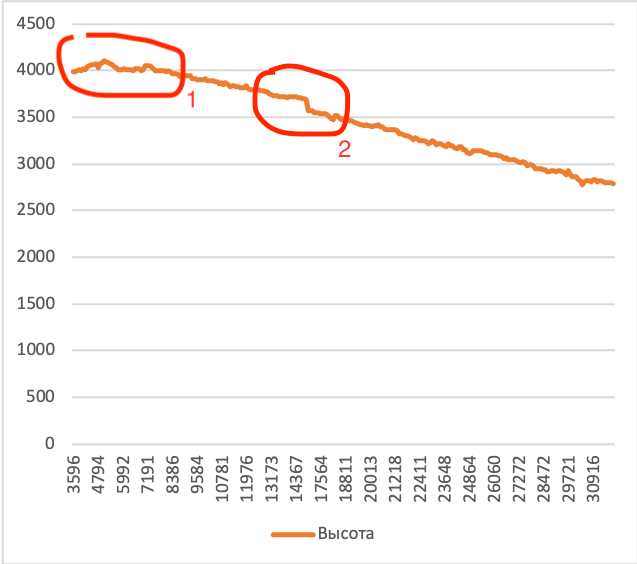
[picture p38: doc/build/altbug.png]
Баги при замере высоты по барометру


1. Момент отделения. Вот так выглядит нестабильность показаний высотомера в условиях сильных турбулентных потоков у обреза двери.

2. Скачок замеров в момент атоматического старта записи трека. Здесь всё устройство подвисает, пока пишет показания за предыдущее время на протяжении около 5 секунд.

### 6. Отсутствие аппаратного компаса.

>В существующих аппаратных модификациях стороны света определяются не по компасу, а по направлению движения. Предполагается, что мы держим устройство перед собой ровно и движемся вперёд.
>
>Такой подход вполне комфортен при движении внутри ЛА. Однако под парашютом такой способ навигации весьма затруднителен в понимании, хоть и используется во многих сущействующих возвращалках.
>
>Установить аппаратный компас в устройство - уже является одной из запланированных задач на ближайшие аппаратные проработки.
>
>В версиях прошивки, начиная с `0.5.3`, север всегда сверху дисплея, если нет аппаратного компаса. Если компас есть, то обозначение севера ориентируется по компасу.

## Также

* [Используемые комплектующие](hardware.md)
* [Планы в развитии](future.md)
* [Сколько стоит и где купить](price.md)

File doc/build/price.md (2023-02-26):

# Хде-Йа - Стоимость и Изготовление

Пока нет планов выходить на коммерческий конвейер.

#### На данный момент план-предложение такое:

* собираю под заказ до 10 устройств (бесплатно! возможно, попрошу Вас оплатить пересылку)
* в ответ ожидаю максимально подробный фидбек (обратную связь, отзывы, пожелания, диагностика)
* если есть желание задонатить - я не против, сумма любая (отсутствие донатов никак не отменяет всего остального тут сказанного, наличие донатов - в значительной степени мотивирует дальнейшую разработку)
* все, кто из этих 10 человек активно участвовал в фидбеке, получит `в обмен` на старый - прибор следующей аппаратной версии бесплатно (возможно, попрошу Вас оплатить пересылку)
* всё под чесное слово

Собираю я сам вручную. Профессиональным монтажником не являюсь, качество пайки можете оценить по [фото](mountq.jpg).

На момент `январь 2022` cебестоимость устройства:

* `v.0.3` = 2500р (больше не собираю),
* `v.0.4` = 3000р (больше не собираю),
* `v.0.5` = 4000р

Это только детали и корпус, без учёта сборки и обслуживания, т.к. делаю сам. Стоимость продолжает увеличиваться при нынешней инфляции и росте курса доллара.

Если готовы участвовать бета-тестером, для заказа - [контакты](../../README.md#контакты).

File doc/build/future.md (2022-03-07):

# Хде-Йа - Планы на ближайшее будушее

## Прошивка

* Переработка доступа к flash-памяти
    
    * исправление подвисаний при записи трека
    
    * подготовка к работе с sd-картой для записи треков и логбука прыжков

* Переработка сетевого стека:
    
    * работа с bluetouth
    
    * подготовка к работе с мобильным приложением

* Переработка отображения навигации
    
    * поддержка аппаратного компаса
    
    * изменение подхода к отображению информации

* Отказ от чипа часов

    Будем использовать внутренние часы чипа навигации.
    
    Использование дополнительного чипа нецелесообразно - только зря занимает место на плате и кушает аккумулятор.

## Аппаратная часть

* Внешняя SD-карта

    Уже давно напрашивается, и в новых аппаратных версиях она точно будет.

* Аппаратный компас

    Пока что я ещё не встретил достуюную аппаратную реализацию, но вариант `более-менее` уже протестирован.

* Внешняя GPS/GLONASS-антенна

    Это будет альтернативой попытке вынести антенну за площадь экрана.

Ближайшая аппаратная версия: [`v.0.5`](../models/03.v.0.5.md)

## Более далёкие планы

* Сменить чип на более энергоэффективный

    Это потянет за собой необходимость прорабатывать уже протестированное и отлаженное. Например WiFi. Всё это муторно и долго, поэтому требует мотивации. В первую очередь мотивация подкрепляется заинтересованностью общественности в данном проекте.

* Мобильное приложение и синхронизация по bluetouth

    Тут ещё больше проблем, чем при смене чипа. Идея очень нужная в реализации, но это всё не быстро.
    
    Но при этом не будет требоваться обновления аппаратной модификации на новую. Текущие версии устройств с новыми прошивками гипотетически заработают без проблем.

* Помощь в программах обучения (пилотирование и т.п.)

    На данный момент это уже возможно, если в прыжке использовать устройство как запись трека, а на замле производить разбор. На практике в таком амплуа оно ещё не проверялось и не отлаживалось.
    
    В какой-то будущей перспективе можно снабжать устройство звуковой сигнализацией. Например, по аналогии с FlySight.

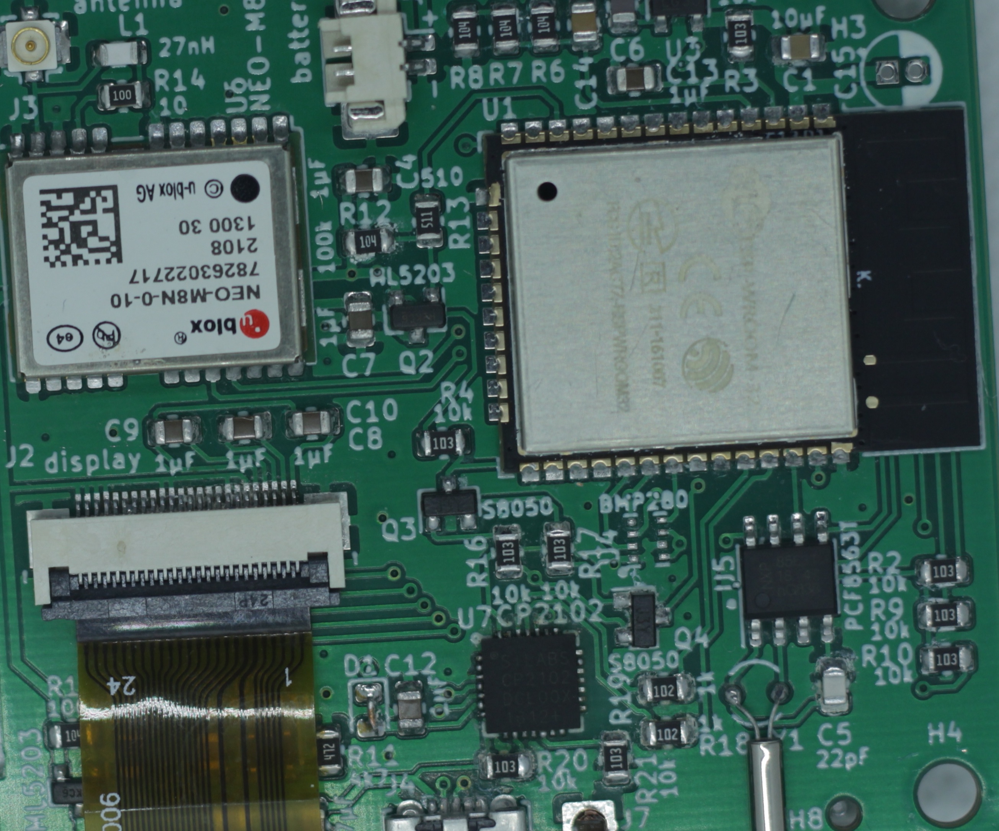
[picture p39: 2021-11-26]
doc/build/mountq.jpg

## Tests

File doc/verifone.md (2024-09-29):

# CP2102 - Проблемы с прошивкой

Устройство при подключении к USB определяется как "Verifone USB to Printer".

Проблема с прошивкой самого чипа CP2102.

## Инструкция по исправлению

1. В MacOS:

    ```
    system_profiler SPUSBDataType
    ```

    Ищем `Product ID` и `Vendor ID`.

2. На сайте https://www.silabs.com/support ищем:

    ```
    install_USBXpress_SDK.exe
    ```

    Устанавливаем.

3. USBXpress Driver: Подставляем PID и VID, генерируем драйвер, либо используем стандартный универсальный драйвер.

4. Там же https://www.silabs.com/support:

    ```
    CP21xxCustomizationUtility
    ```
    
    либо: USBXpress Device Customization Utility (из п.2)

    Должно появиться устройство. Если устройство не видно, надо сгенерировать драйвер ещё раз.

5. Меняем:
    
    ```
    Vendor ID: 0x10c4  (Silicon Laboratories, Inc.)
    Product ID: 0xea60
    Power: 32
    Power Mode: 00 - Bus powered
    Realese Version: 0100
    Product Description: CP2102 USB to UART Bridge Controller
    Serial: 0001
    Lock Device: 00 - Device is unlocked
    ```

6. Жмём `Program Device`

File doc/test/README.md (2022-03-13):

# Хде-Йа - Экспериментальные наработки

Местами это выглядит как колхоз, поэтому ничего из этого раздела `не делается по умолчанию`, только по запросу.

## Качество GPS/GLONASS сигнала

Пока что приём сигнала в ЛА, особенно, на высоте выше 3000м оставляет желать лучшего.

### Сейчас антенна выглядит вот так

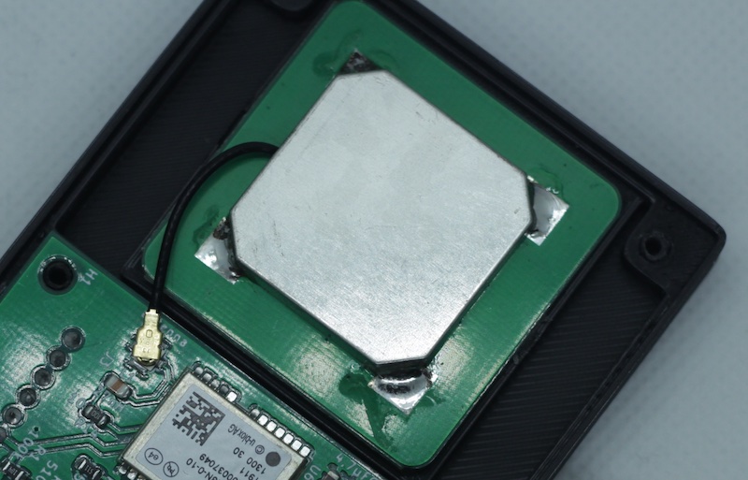
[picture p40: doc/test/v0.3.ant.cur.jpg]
Текущий вид антенны на v.0.3


### Случайно успешный эксперимент на v.0.3

Результат такого колхоза - гораздо более уверенный приём, даже в квартире, где без доработки ничего не ловило.

К сожалению, я не радиолюбитель и мои познания в радиоприёме очень слабы. Я не знаю, почему стало лучше, но факт, что стало ловить заметно лучше.

Пока доработку только тестирую. В месте пайки этой доработки к оригинальной антенне - очень слабое там место, и от вибрации оно может отвалиться. Пока держится.

Доработка антенны
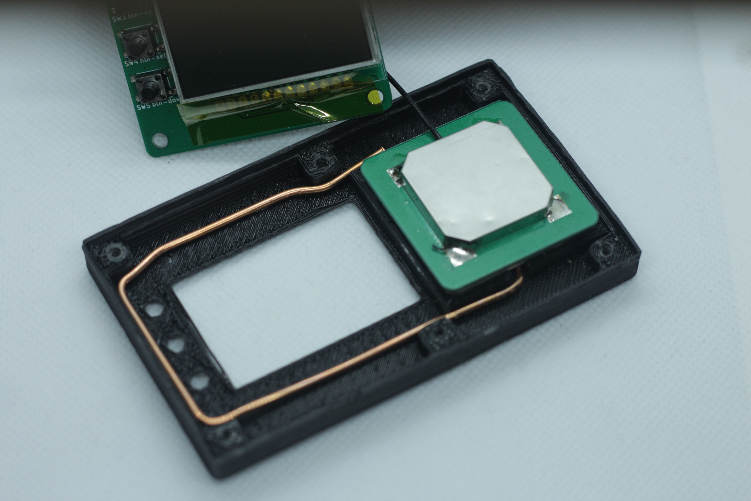
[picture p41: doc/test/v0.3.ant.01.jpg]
Доработка антенны - вид в корпусе


## Аппаратный компас

На данный момент - в процессе разработки.

### Как сейчас работает компас

Включается в меню `Настройки` -> `Использовать компас`.

Если компас выключен, то север на приборе будет всегда сверху.

Если компас включен, то вся "карта" будет поворачиваться в направлении севера.

### Стабильность

* Как и обычный стрелочный компас, цифровой компас точно так же сильно искажает показания
при любом физическом воздействии (ускорение, тряска, удары). Чем в бОльшем физическом покое будет устройство,
тем валидней будут показания.

* Реальная точность показаний сейчас изучается.

### Как выглядит доработка для v.0.4

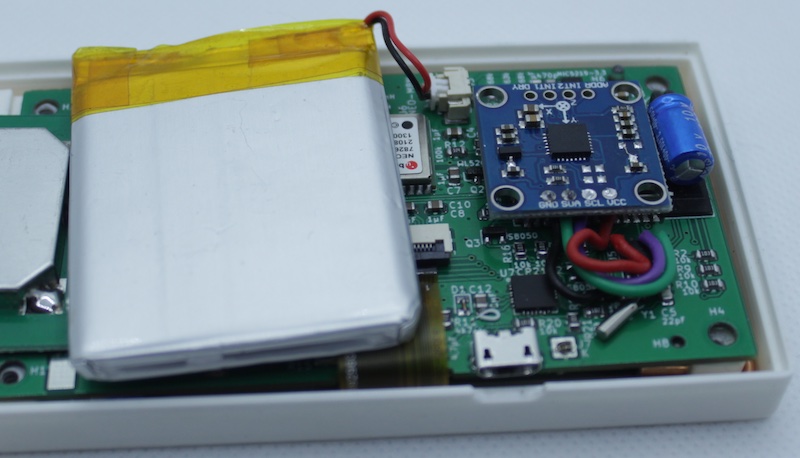
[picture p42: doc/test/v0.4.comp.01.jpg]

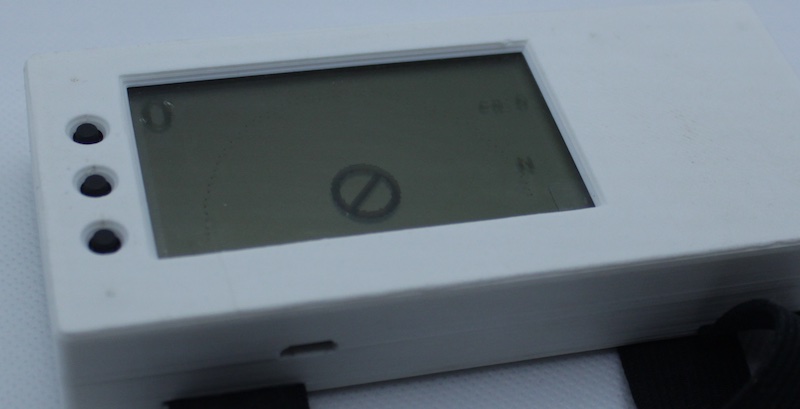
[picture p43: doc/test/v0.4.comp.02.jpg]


Для аппаратной версии `v.0.3` доработка примерно такая же.

### Где взять прошивку

Поддерживается прошивкой, начиная с [v0.6.0](https://github.com/cliffanet/xdeya-altimeter/releases/tag/v0.6.0)

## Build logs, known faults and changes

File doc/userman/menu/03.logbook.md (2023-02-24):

# LogBook (ЛогБук)

Сначала мы попадаем в список прыжков. Более поздний прыжок находится выше. Для каждого прыжка отображается `Время/Дата` и `Номер прыжка`.

Нажав на прыжок, увидим более подробную информацию о нём. И можно перемещаться к более ранним и более поздним прыжкам кнопками `вверх` и `вниз`.

Отображаемая информация:

* Номер прыжка (в самом вверху в заголовке)
* Дата/время (момент отделения от ЛА)
* Высота отделения (м)
* Высота раскрытия парашюта (скорость падения снижается до 10 м/с)
* Длительность взлёта (мин:сек)
* Длительность свободного падения (сек)
* Длительность парашютирования (сек)

Для каждого прыжка сохраняются четыре точки:

* Взлёт (отрыв от земли)
* Отделение от ЛА
* Раскрытие парашюта
* Приземление

Для каждой точки сохраняется:

* Дата/время
* Высота по барометру
* Все навигационные параметры

Выход из `подробной информации` обратно в `список` производится `средней кнопкой`.

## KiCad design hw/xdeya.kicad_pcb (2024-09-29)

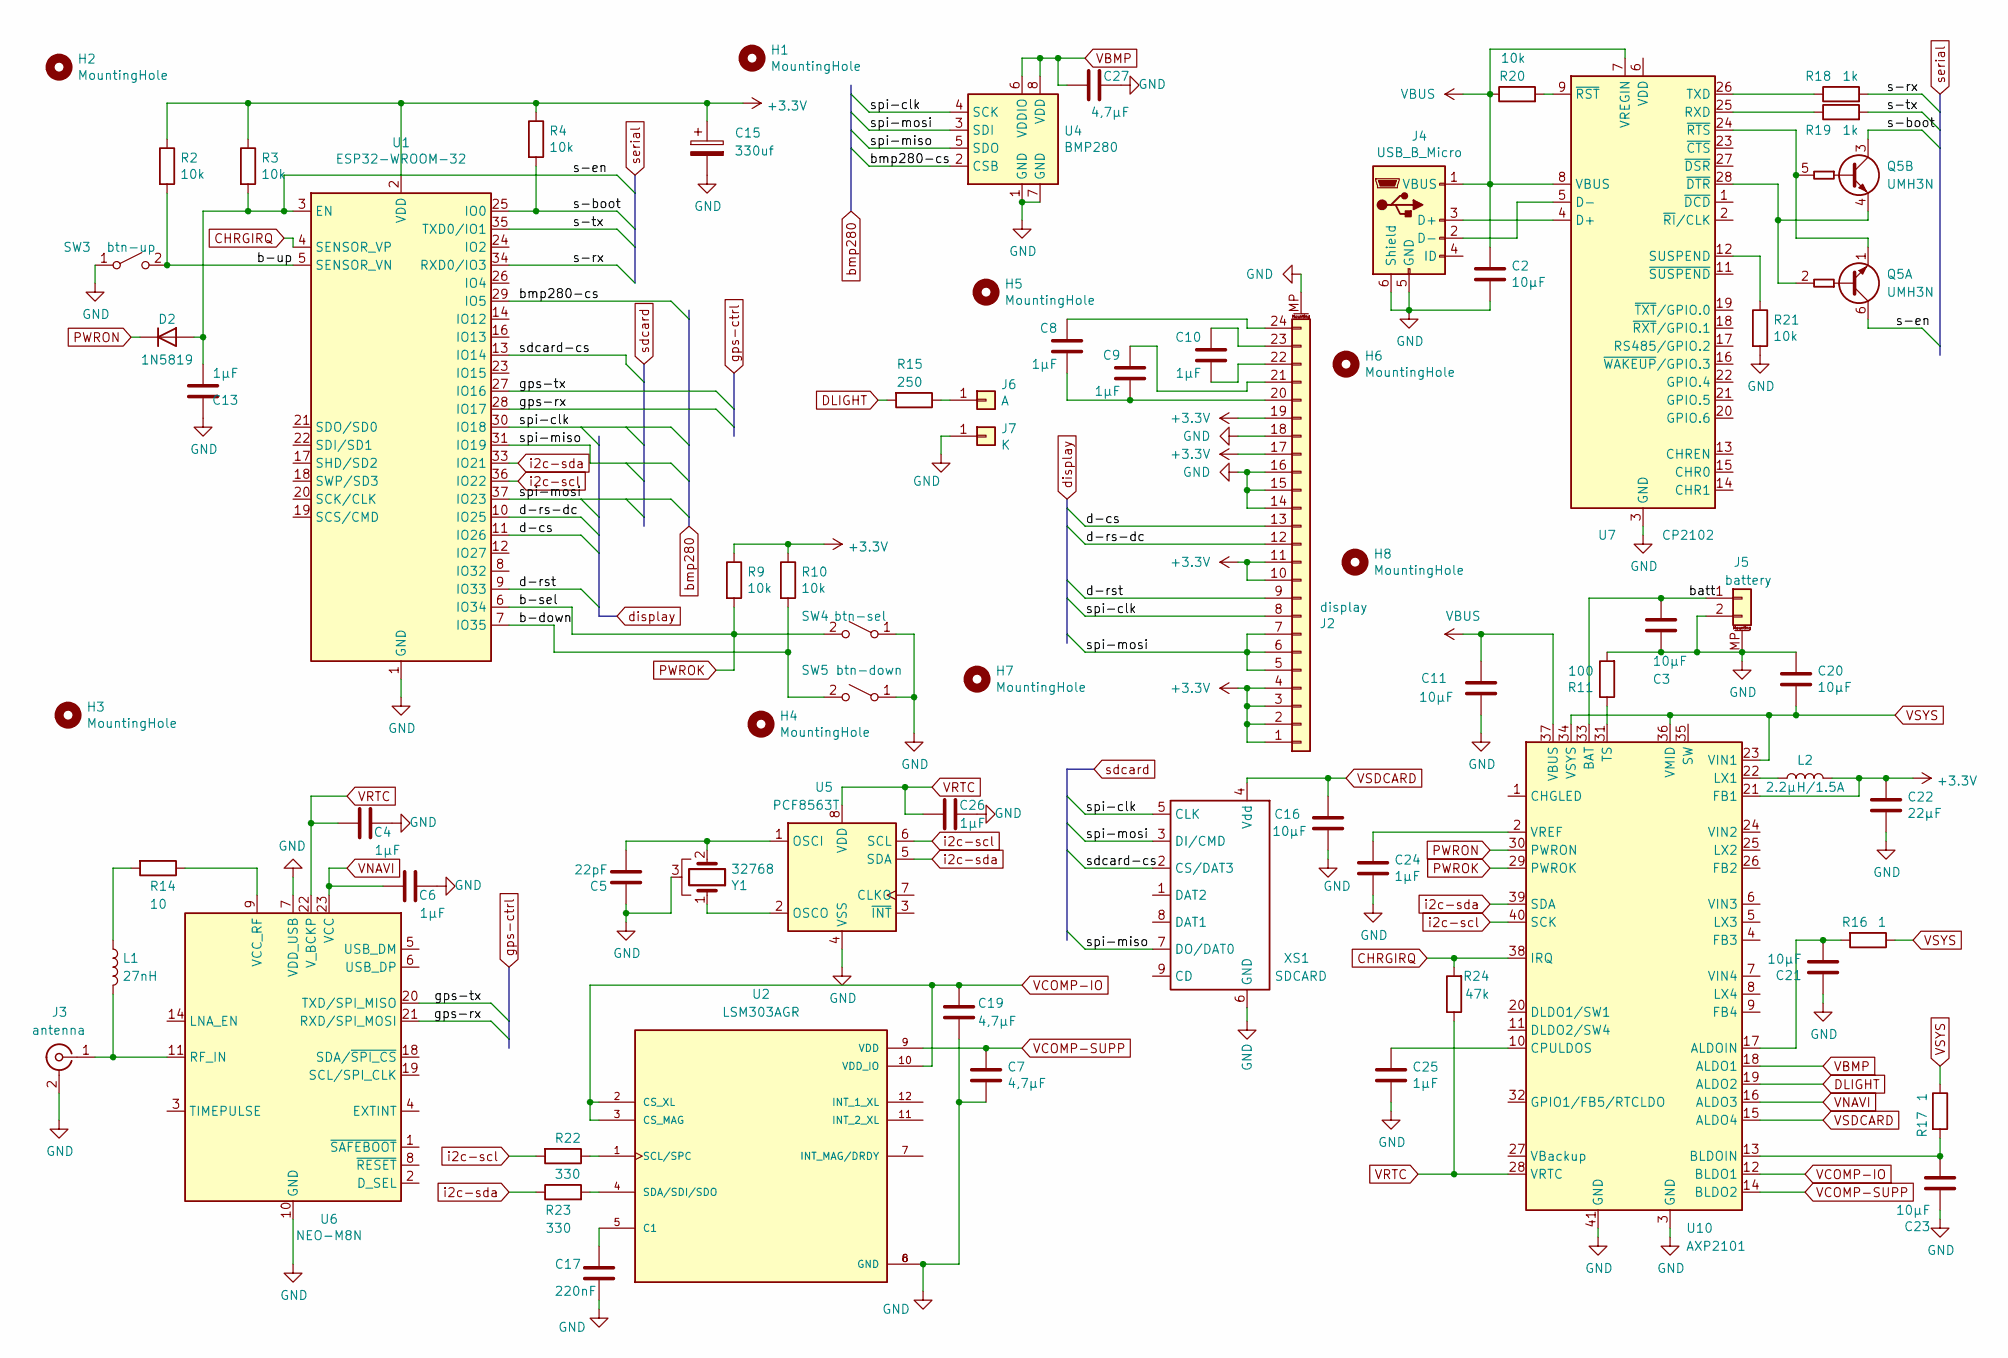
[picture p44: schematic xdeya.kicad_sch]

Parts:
C2, C3, C11, C16, C20, C21, C23: 10μF; C_0805_2012Metric
C4, C6, C8, C9, C10, C13, C24, C25, C26: 1μF; C_0805_2012Metric
C5: 22pF; C_0805_2012Metric
C7, C19, C27: 4,7μF; C_0805_2012Metric
C15: 330uf; CP_EIA-7343-20_Kemet-V
C17: 220nF; C_0805_2012Metric
C22: 22μF; C_0805_2012Metric
D2: 1N5819; D_SOD-323
H1, H2, H3, H4: MountingHole; MountingHole_3.2mm_M3
H5, H6: MountingHole; MountingHole_2.2mm_M2
H7, H8: MountingHole; MountingHole_1.5
J2: display; TE_2-1734839-4_1x24-1MP_P0.5mm_Horizontal
J3: antenna; SMA_Molex_73251-2200_Horizontal
J4: USB_B_Micro; USB_Micro-B_Molex-105017-0001
J5: battery; Molex_PicoBlade_53261-0271_1x02-1MP_P1.25mm_Horizontal
J6: A; SolderWire-1sqmm_1x01_D1.4mm_OD2.7mm
J7: K; SolderWire-1sqmm_1x01_D1.4mm_OD2.7mm
L1: 27nH; L_0805_2012Metric
L2: 2.2μH/1.5A; L_Wurth_WE-LQSH-3012
Q5: UMH3N; SOT-363_SC-70-6
R2, R3, R4, R9, R10, R20, R21: 10k; R_0805_2012Metric
R11: 100; R_0805_2012Metric
R14: 10; R_0805_2012Metric
R15: 250; R_0805_2012Metric
R16, R17: 1; R_0805_2012Metric
R18, R19: 1k; R_0805_2012Metric
R22, R23: 330; R_0805_2012Metric
R24: 47k; R_0805_2012Metric
SW3: btn-up; SW_Push_1P1T_NO_6x6mm_H9.5mm
SW4: btn-sel; SW_Push_1P1T_NO_6x6mm_H9.5mm
SW5: btn-down; SW_Push_1P1T_NO_6x6mm_H9.5mm
U1: ESP32-WROOM-32
U2: LSM303AGR; PQFN50P200X200X100-12N; PARTREV 10
U4: BMP280; Bosch_LGA-8_2x2.5mm_P0.65mm_ClockwisePinNumbering
U5: PCF8563T; SOIC-8_3.9x4.9mm_P1.27mm
U6: NEO-M8N; ublox_NEO
U7: CP2102; QFN-28-1EP_5x5mm_P0.5mm_EP3.35x3.35mm
U10: AXP2101; QFN-40-1EP_5x5mm_P0.4mm_EP3.6x3.6mm_ThermalVias
XS1: SDCARD; Conn_uSDcard
Y1: 32768; Crystal_DS26_D2.0mm_L6.0mm_Horizontal_1EP_style2

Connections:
+3.3V: C15.1, C22.1, J2.1, J2.2, J2.3, J2.4, J2.10, J2.11, J2.17, J2.19, L2.2, R2.1, R3.1, R4.1, R9.1, R10.1, U1.2 (VDD), U10.21 (FB1)
/b-down: R10.2, SW5.2 (B), U1.7 (IO35)
/b-up: R2.2, SW3.2 (B), U1.5 (SENSOR_VN)
/batt: C3.1, J5.1, U10.33 (BAT)
/bmp280-cs: U1.29 (IO5), U4.2 (CSB)
/d-cs: J2.13, U1.11 (IO26)
/d-rs-dc: J2.12, U1.10 (IO25)
/d-rst: J2.9, U1.9 (IO33)
/gps-rx: U1.28 (IO17), U6.21 (RXD/SPI_MOSI)
/gps-tx: U1.27 (IO16), U6.20 (TXD/SPI_MISO)
/s-boot: Q5.3 (C2), R4.2, U1.25 (IO0)
/s-en: C13.2, D2.2 (A), Q5.6 (C1), R3.2, U1.3 (EN)
/s-rx: R18.2, U1.34 (RXD0/IO3)
/s-tx: R19.2, U1.35 (TXD0/IO1)
/sdcard-cs: U1.13 (IO14), XS1.2 (CS/DAT3)
/spi-clk: J2.8, U1.30 (IO18), U4.4 (SCK), XS1.5 (CLK)
/spi-miso: U1.31 (IO19), U4.5 (SDO), XS1.7 (DO/DAT0)
/spi-mosi: J2.5, J2.6, J2.7, U1.37 (IO23), U4.3 (SDI), XS1.3 (DI/CMD)
CHRGIRQ: R24.2, U1.4 (SENSOR_VP), U10.38 (IRQ)
DLIGHT: R15.2, U10.19 (ALDO2)
GND: C2.2, C3.2, C4.2, C5.1, C6.2, C7.2, C11.1, C13.1, C15.2, C16.2, C17.2, C19.2, C20.1, C21.1, C22.2, C23.1, C24.2, C25.2, C26.2, C27.2, J2.14, J2.15, J2.16, J2.18, J2.MP (MountPin), J3.2 (Ext), J4.5 (GND), J4.6 (Shield), J5.2, J5.MP (MountPin), J7.1, R11.2, R21.2, SW3.1 (A), SW4.1 (A), SW5.1 (A), U1.1 (GND), U1.15 (GND), U1.38 (GND), U1.39 (GND), U2.6 (GND), U2.8 (GND), U4.1 (GND), U4.7 (GND), U5.4 (VSS), U6.7 (VDD_USB), U6.10 (GND), U6.12 (GND), U6.13 (GND), U6.24 (GND), U7.3 (GND), U7.29 (GND), U10.3 (GND), U10.41 (GND), XS1.6 (GND), Y1.3
unnamed: C8.1, C9.1, J2.20
unnamed: C9.2, J2.21
unnamed: C10.1, J2.22
unnamed: C10.2, J2.23
unnamed: C8.2, J2.24
unnamed: J3.1 (In), L1.2, U6.11 (RF_IN)
unnamed: J4.3 (D+), U7.4 (D+)
unnamed: J4.2 (D-), U7.5 (D-)
unnamed: J6.1, R15.1
unnamed: L1.1, R14.2
unnamed: Q5.2 (B1), Q5.4 (E2), U7.28 (~DTR)
unnamed: Q5.1 (E1), Q5.5 (B2), U7.24 (~RTS)
unnamed: C17.1, U2.5 (C1)
unnamed: R22.1, U2.1 (SCL/SPC)
unnamed: R23.2, U2.4 (SDA/SDI/SDO)
unnamed: C5.2, U5.1 (OSCI), Y1.2
unnamed: U5.2 (OSCO), Y1.1
unnamed: R14.1, U6.9 (VCC_RF)
unnamed: R19.1, U7.25 (RXD)
unnamed: R21.1, U7.12 (SUSPEND)
unnamed: R18.1, U7.26 (TXD)
unnamed: R20.2, U7.9 (~RST)
unnamed: C21.2, R16.2, U10.17 (ALDOIN)
unnamed: C23.2, R17.2, U10.13 (BLDOIN)
unnamed: C25.1, U10.10 (CPULDOS)
unnamed: L2.1, U10.22 (LX1)
unnamed: R11.1, U10.31 (TS)
unnamed: C24.1, U10.2 (VREF)
PWROK: R9.2, SW4.2 (B), U1.6 (IO34), U10.29 (PWROK)
PWRON: D2.1 (K), U10.30 (PWRON)
VBMP: C27.1, U4.6 (VDDIO), U4.8 (VDD), U10.18 (ALDO1)
VBUS: C2.1, C11.2, J4.1 (VBUS), R20.1, U7.7 (VREGIN), U7.8 (VBUS), U10.37 (VBUS)
VCOMP-IO: C19.1, U2.2 (CS_XL), U2.3 (CS_MAG), U2.10 (VDD_IO), U10.12 (BLDO1)
VCOMP-SUPP: C7.1, U2.9 (VDD), U10.14 (BLDO2)
VNAVI: C6.1, U6.23 (VCC), U10.16 (ALDO3)
VRTC: C4.1, C26.1, R24.1, U5.8 (VDD), U6.22 (V_BCKP), U10.28 (VRTC)
VSDCARD: C16.1, U10.15 (ALDO4), XS1.4 (Vdd)
VSYS: C20.2, R16.1, R17.1, U10.23 (VIN1), U10.34 (VSYS), U10.36 (VMID)
i2c-scl: R22.2, U1.36 (IO22), U5.6 (SCL), U10.40 (SCK)
i2c-sda: R23.1, U1.33 (IO21), U5.5 (SDA), U10.39 (SDA)

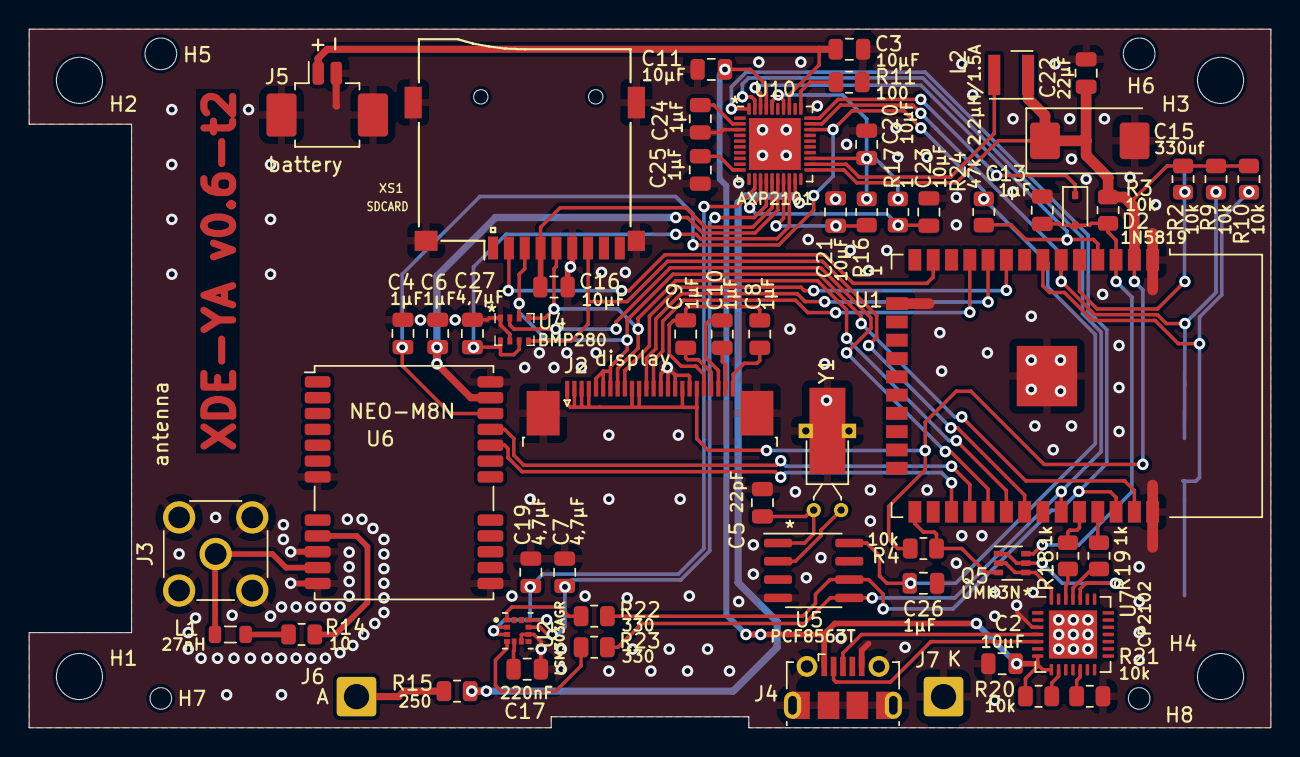
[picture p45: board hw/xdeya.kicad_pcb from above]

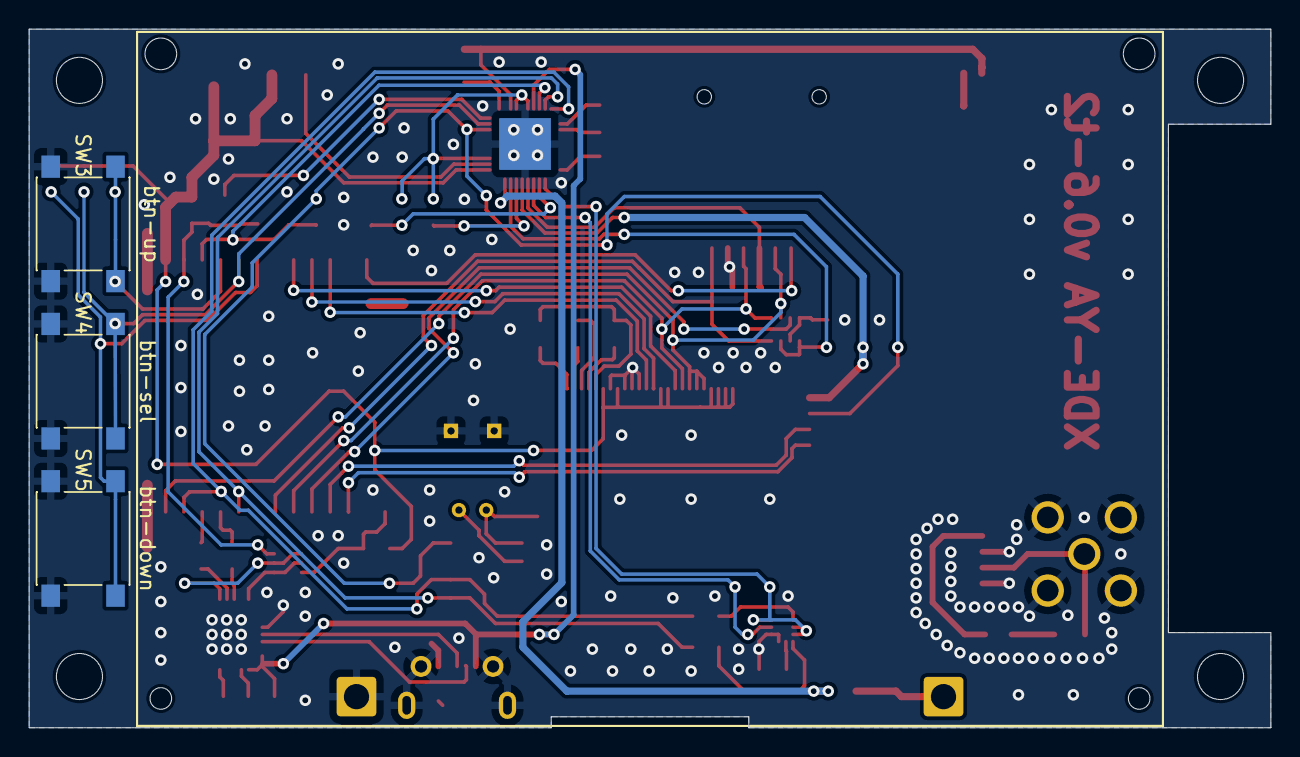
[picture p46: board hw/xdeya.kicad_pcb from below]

Board: 2 copper layers, 86.2 x 48.5 mm, 70 parts (3 on the bottom side), 61 nets.

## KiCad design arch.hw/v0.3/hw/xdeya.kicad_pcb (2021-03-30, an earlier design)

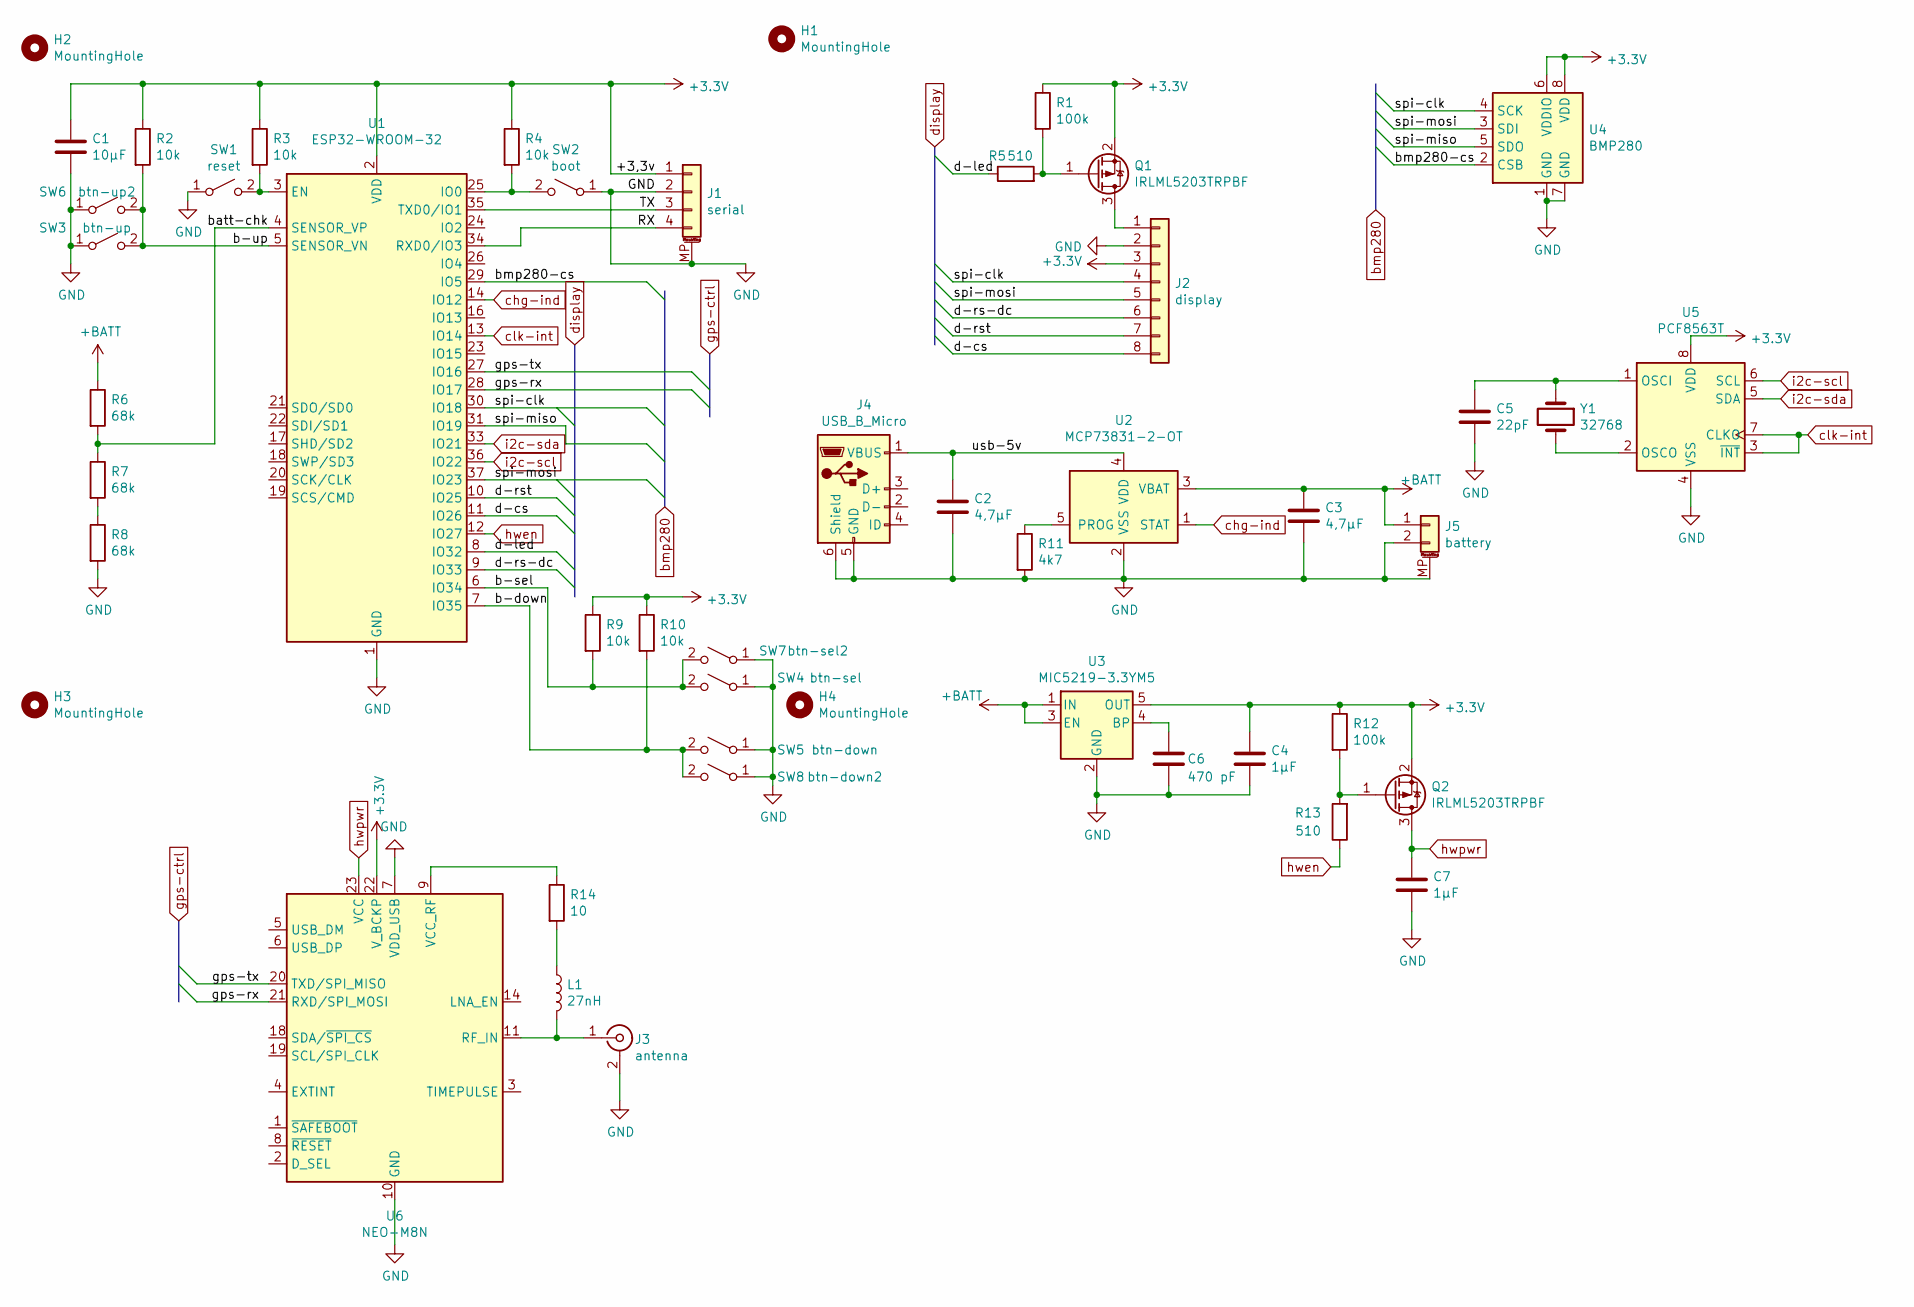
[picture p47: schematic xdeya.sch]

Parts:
C1: 10μF; C_0805_2012Metric
C2, C3: 4,7μF; C_0805_2012Metric
C4, C7: 1μF; C_0805_2012Metric
C5: 22pF; C_0805_2012Metric
C6: 470 pF; C_0805_2012Metric
H1, H2, H3, H4: MountingHole; MountingHole_3.2mm_M3
J1: serial; Molex_PicoBlade_53398-0471_1x04-1MP_P1.25mm_Vertical
J2: display; PinHeader_1x08_P2.54mm_Vertical
J3: antenna; U.FL_Molex_MCRF_73412-0110_Vertical
J4: USB_B_Micro; USB_Micro-B_Molex-105017-0001
J5: battery; Molex_PicoBlade_53261-0271_1x02-1MP_P1.25mm_Horizontal
L1: 27nH; L_0805_2012Metric
Q1, Q2: IRLML5203TRPBF; SOT-23
R1, R12: 100k; R_0805_2012Metric
R2, R3, R4, R9, R10: 10k; R_0805_2012Metric
R5, R13: 510; R_0805_2012Metric
R6, R7, R8: 68k; R_0805_2012Metric
R11: 4k7; R_0805_2012Metric
R14: 10; R_0805_2012Metric
SW1: reset; SW_Push_SPST_NO_Alps_SKRK
SW2: boot; SW_Push_SPST_NO_Alps_SKRK
SW3: btn-up; SW_SPST_PTS810
SW4: btn-sel; SW_SPST_PTS810
SW5: btn-down; SW_SPST_PTS810
SW6: btn-up2; SW_Push_1P1T_NO_6x6mm_H9.5mm
SW7: btn-sel2; SW_Push_1P1T_NO_6x6mm_H9.5mm
SW8: btn-down2; SW_Push_1P1T_NO_6x6mm_H9.5mm
U1: ESP32-WROOM-32
U2: MCP73831-2-OT; SOT-23-5
U3: MIC5219-3.3YM5; SOT-23-5
U4: BMP280; Bosch_LGA-8_2x2.5mm_P0.65mm_ClockwisePinNumbering
U5: PCF8563T; SOIC-8_3.9x4.9mm_P1.27mm
U6: NEO-M8N; ublox_NEO
Y1: 32768; Crystal_AT310_D3.0mm_L10.0mm_Vertical

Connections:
+3V3: C1.1, C4.1, J1.1, J2.3, Q1.2 (S), Q2.2 (S), R1.1, R2.1, R3.1, R4.1, R9.1, R10.1, R12.1, U1.2 (VDD), U3.5 (OUT), U4.6 (VDDIO), U4.8 (VDD), U5.8 (VDD), U6.22 (V_BCKP)
+BATT: C3.1, J5.1, R6.1, U2.3 (VBAT), U3.1 (IN), U3.3 (EN)
/RX: J1.4, U1.34 (RXD0/IO3)
/TX: J1.3, U1.35 (TXD0/IO1)
/b-down: R10.2, SW5.2 (B), SW8.2 (B), U1.7 (IO35)
/b-sel: R9.2, SW4.2 (B), SW7.2 (B), U1.6 (IO34)
/b-up: R2.2, SW3.2 (B), SW6.2 (B), U1.5 (SENSOR_VN)
/batt-chk: R6.2, R7.1, U1.4 (SENSOR_VP)
/bmp280-cs: U1.29 (IO5), U4.2 (CSB)
/d-cs: J2.8, U1.11 (IO26)
/d-led: R5.1, U1.8 (IO32)
/d-rs-dc: J2.6, U1.9 (IO33)
/d-rst: J2.7, U1.10 (IO25)
/gps-rx: U1.28 (IO17), U6.21 (RXD/SPI_MOSI)
/gps-tx: U1.27 (IO16), U6.20 (TXD/SPI_MISO)
/spi-clk: J2.4, U1.30 (IO18), U4.4 (SCK)
/spi-miso: U1.31 (IO19), U4.5 (SDO)
/spi-mosi: J2.5, U1.37 (IO23), U4.3 (SDI)
/usb-5v: C2.1, J4.1 (VBUS), U2.4 (VDD)
GND: C1.2, C2.2, C3.2, C4.2, C5.2, C6.2, C7.2, J1.2, J1.MP (MountPin), J2.2, J3.2 (Ext), J4.5 (GND), J4.6 (Shield), J5.2, J5.MP (MountPin), R8.2, R11.2, SW1.1 (A), SW2.1 (A), SW3.1 (A), SW4.1 (A), SW5.1 (A), SW6.1 (A), SW7.1 (A), SW8.1 (A), U1.1 (GND), U1.15 (GND), U1.38 (GND), U1.39 (GND), U2.2 (VSS), U3.2 (GND), U4.1 (GND), U4.7 (GND), U5.4 (VSS), U6.7 (VDD_USB), U6.10 (GND), U6.12 (GND), U6.13 (GND), U6.24 (GND)
unnamed: C5.1, U5.1 (OSCI), Y1.1
unnamed: C6.1, U3.4 (BP)
unnamed: J2.1, Q1.3 (D)
unnamed: J3.1 (In), L1.2, U6.11 (RF_IN)
unnamed: L1.1, R14.2
unnamed: Q1.1 (G), R1.2, R5.2
unnamed: Q2.1 (G), R12.2, R13.2
unnamed: R3.2, SW1.2 (B), U1.3 (EN)
unnamed: R4.2, SW2.2 (B), U1.25 (IO0)
unnamed: R7.2, R8.1
unnamed: R11.1, U2.5 (PROG)
unnamed: R14.1, U6.9 (VCC_RF)
unnamed: U5.2 (OSCO), Y1.2
chg-ind: U1.14 (IO12), U2.1 (STAT)
clk-int: U1.13 (IO14), U5.3 (~INT~), U5.7 (CLKO)
hwen: R13.1, U1.12 (IO27)
hwpwr: C7.1, Q2.3 (D), U6.23 (VCC)
i2c-scl: U1.36 (IO22), U5.6 (SCL)
i2c-sda: U1.33 (IO21), U5.5 (SDA)

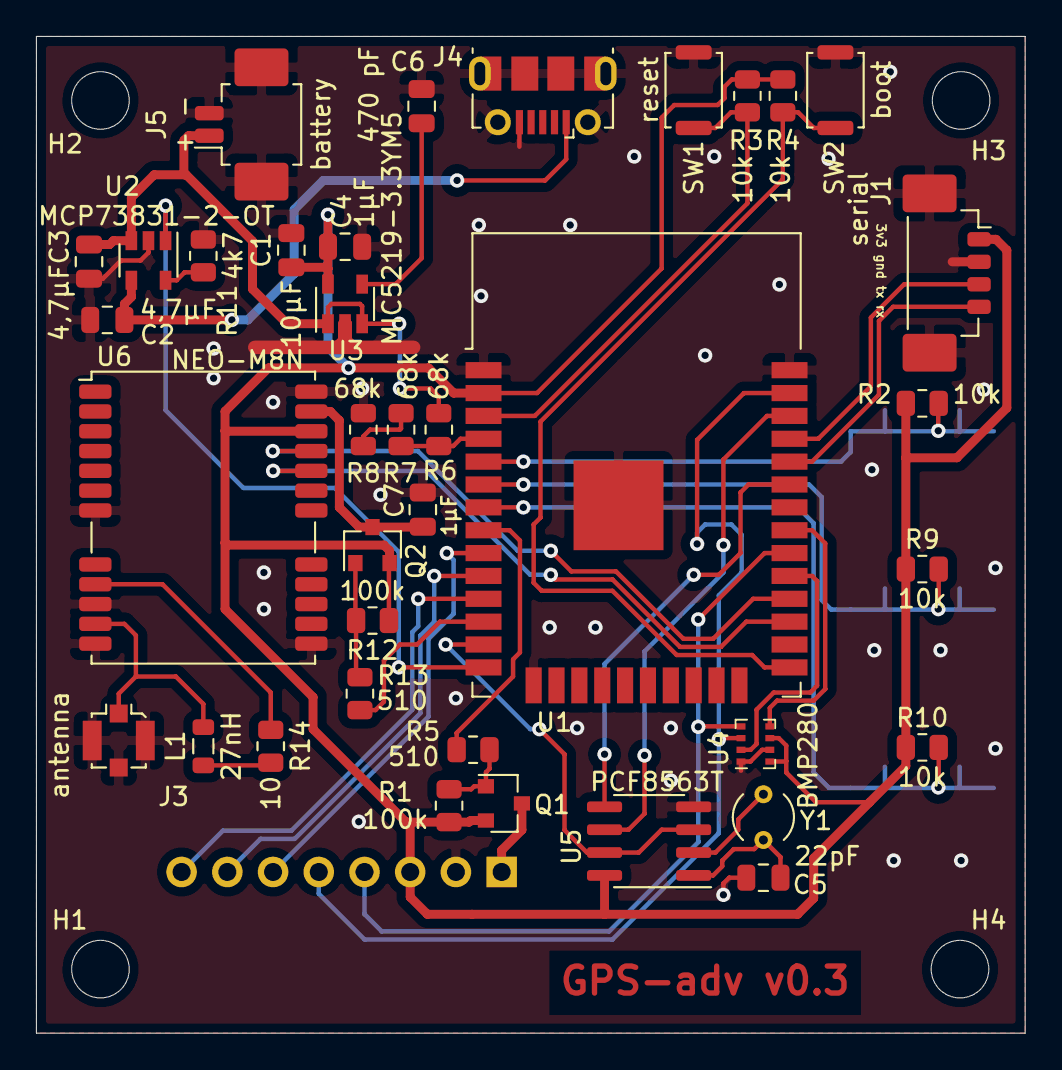
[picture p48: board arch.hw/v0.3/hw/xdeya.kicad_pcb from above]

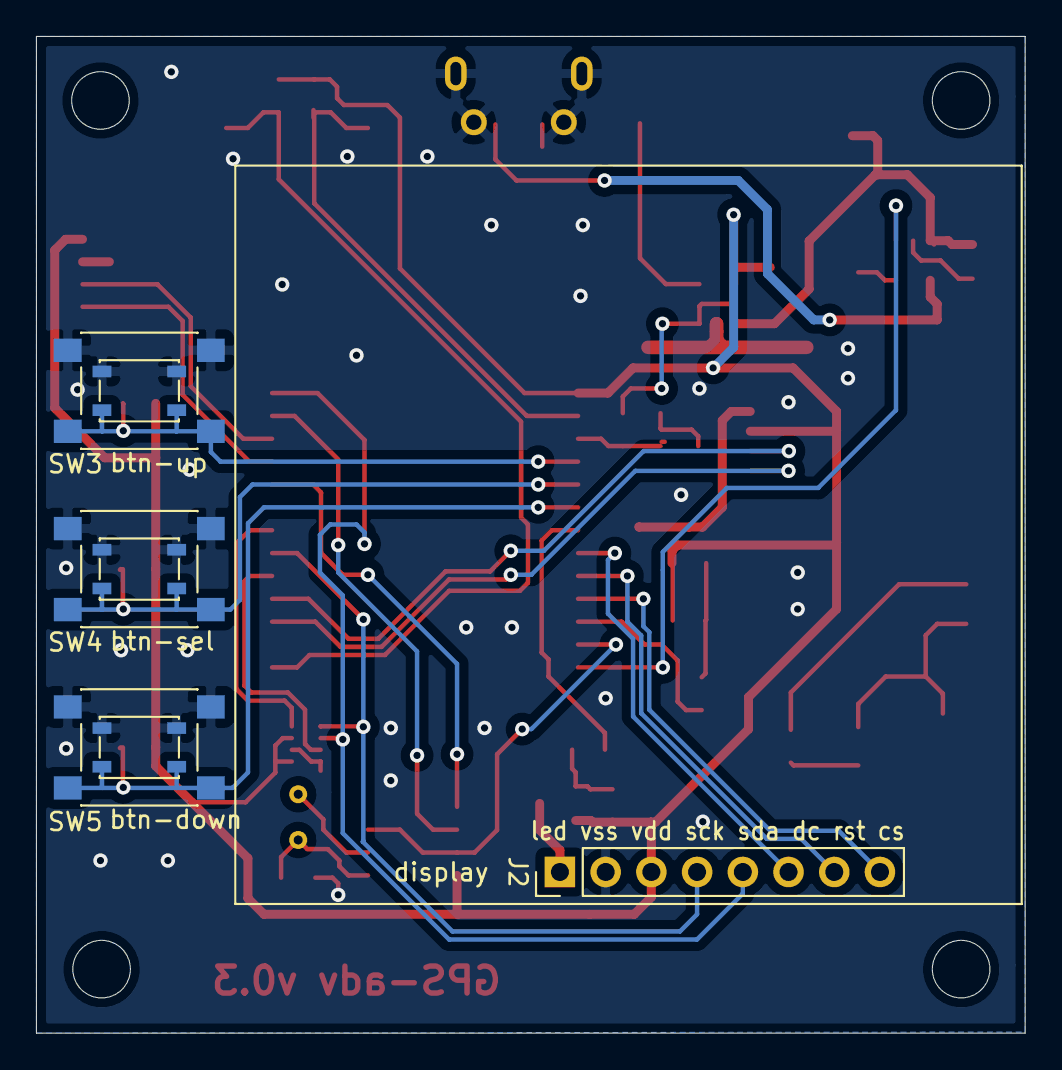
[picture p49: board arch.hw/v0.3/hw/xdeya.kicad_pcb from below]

Board: 2 copper layers, 54.9 x 55.4 mm, 48 parts (7 on the bottom side), 39 nets.

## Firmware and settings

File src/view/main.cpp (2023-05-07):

#include "main.h"

#include "menu.h"
#include "../log.h"
#include "../power.h" // pwrBattRaw()
#include "../clock.h"
#include "../jump/proc.h"
#include "../jump/track.h"
#include "../navi/proc.h"
#include "../cfg/point.h"

static RTC_DATA_ATTR uint8_t mode = MODE_MAIN_ALTNAV; // Текущая страница отображения, сохраняется при переходе в меню

static void btnDo(uint8_t op) {
    switch (op) {
        case BTNDO_LIGHT:
            CONSOLE("[%d] displayLightTgl", op);
            displayLightTgl();
            break;
            
        case BTNDO_NAVPWR:
            CONSOLE("[%d] gpsPwrTgl", op);
            gpsPwrTgl();
            break;
            
        case BTNDO_TRKREC:
            CONSOLE("[%d] trkStart/trkStop", op);
            if (trkRunning())
                trkStop();
            else
                trkStart(TRK_RUNBY_HAND);
            break;
            
        case BTNDO_PWROFF:
            CONSOLE("[%d] pwrOff", op);
            pwrOff();
            break;
    }
}

void ViewMain::btnLong(btn_code_t btn) {
    switch (btn) {
        case BTN_UP:
            btnDo(cfg.d().btndo_up);
            return;

        case BTN_SEL:
            setViewMenu();
            return;
            
        case BTN_DOWN:
            btnDo(cfg.d().btndo_down);
            return;
    }
}

void ViewMain::drawState(U8G2 &u8g2) {
    u8g2.setDrawColor(1);
#if HWVER >= 3
    uint8_t blev = pwrBattLevel();
    if ((blev > 0) || isblink()) {
        u8g2.setFont(u8g2_font_battery19_tn);
        u8g2.setFontDirection(1);
        u8g2.drawGlyph(0, 0, '0' + blev);
        u8g2.setFontDirection(0);
    }
    if (pwrBattCharge()) {
        u8g2.setFont(u8g2_font_open_iconic_embedded_1x_t);
        u8g2.drawGlyph(0, 20, 'C');
    }
#endif
    
    u8g2.setFont(u8g2_font_helvB08_tr);

#if HWVER == 2
    char s[10];
    sprintf_P(s, PSTR("%d"), pwrBattRaw());
    u8g2.drawStr(0, 8, s);
#endif

#ifdef USE4BUTTON
// нажатие на дополнительную 4ую кнопку
    if (btn4Pushed()) {
        u8g2.drawBox(0, 7, 10, 10);
        u8g2.setDrawColor(0);
    }
#endif
    
    if (trkRunning() && isblink())
        u8g2.drawGlyph(0, u8g2.getDisplayHeight()-10, 'R');
    
#ifdef USE4BUTTON
    u8g2.setDrawColor(1);
#endif
}

void ViewMain::drawClock(U8G2 &u8g2) {
    if (!tmValid())
        return;
    
    char s[10];
    sprintf_P(s, PSTR("%d:%02d"), tmNow().h, tmNow().m);

    u8g2.setDrawColor(1);
#if HWVER < 4
    u8g2.setFont(u8g2_font_tom_thumb_4x6_mn);
    u8g2.drawStr(53, 6, s);
#else // if HWVER < 4
    u8g2.setFont(u8g2_font_amstrad_cpc_extended_8n);
    u8g2.drawStr(80, 10, s);
#endif // if HWVER < 4
}

void ViewMain::drawAlt(U8G2 &u8g2, int x, int y) {
    auto &ac = altCalc();
    if (ac.state() <= ACST_INIT)
        return;
    
    int16_t alt = round(ac.alt() + cfg.d().altcorrect);
    int16_t o = alt % ALT_STEP;
    alt -= o;
    if (abs(o) > ALT_STEP_ROUND) alt+= o >= 0 ? ALT_STEP : -ALT_STEP;

    char s[10];
    snprintf_P(s, sizeof(s), PSTR("%d"), alt);

    if (x < 0)
        x = u8g2.getDisplayWidth()-u8g2.getStrWidth(s) + x + 1;
    u8g2.drawStr(x, y, s);
}

void ViewMain::drawNavSat(U8G2 &u8g2) {
    auto &gps = gpsInf();
    char s[50];
    
    u8g2.setFont(menuFont);
    
    switch (gpsState()) {
        case NAV_STATE_OFF:
            strcpy_P(s, PTXT(MAIN_NAVSTATE_OFF));
            break;
        
        case NAV_STATE_INIT:
            strcpy_P(s, PTXT(MAIN_NAVSTATE_INIT));
            break;
        
        case NAV_STATE_FAIL:
            strcpy_P(s, PTXT(MAIN_NAVSTATE_INITFAIL));
            break;
        
        case NAV_STATE_NODATA:
            strcpy_P(s, PTXT(MAIN_NAVSTATE_NODATA));
            break;
        
        case NAV_STATE_OK:
            sprintf_P(s, PTXT(MAIN_NAVSTATE_SATCOUNT), gps.numSV);
            break;
    }
    u8g2.drawTxt(0, u8g2.getDisplayHeight()-1, s);
}

void ViewMain::drawNavDist(U8G2 &u8g2, int y) {
    auto &gps = gpsInf();
    if (!gps.validLocation() || !gps.validPoint() || !pnt.numValid() || !pnt.cur().used)
        return;
    
    char s[10];
    double dist =
        gpsDistance(
            gps.getLat(),
            gps.getLon(),
            pnt.cur().lat, 
            pnt.cur().lng
        );

    if (dist < 950) 
        sprintf_P(s, PSTR("%0.0fm"), dist);
    else if (dist < 9500) 
        sprintf_P(s, PSTR("%0.1fk"), dist/1000);
    else if (dist < 950000) 
        sprintf_P(s, PSTR("%0.0fk"), dist/1000);
    else
        sprintf_P(s, PSTR("%0.2fM"), dist/1000000);

    u8g2.drawStr(u8g2.getDisplayWidth() - u8g2.getStrWidth(s), y, s);
}

void setViewMain(int8_t m, bool save) {
    menuClear();
    
    if (m <= MODE_MAIN_NONE)
        return;
    
    if (m == MODE_MAIN_LAST) {
        if ((mode < MODE_MAIN_MIN) || (mode > MODE_MAIN_MAX))
            mode = MODE_MAIN_ALTNAV;
        m = mode;
    }
    else
    if (save && (m >= MODE_MAIN_MIN) && (m <= MODE_MAIN_MAX))
        mode = m;
    
    switch (m) {
        case MODE_MAIN_ALTNAV:
            CONSOLE("click to gps-alt");
            setViewMainAltNav();
            break;
            
        case MODE_MAIN_ALT:
            CONSOLE("click to alt");
            setViewMainAlt();
            break;
        
        case MODE_MAIN_NAV:
            CONSOLE("click to nav");
            setViewMainNav();
            break;
        
        case MODE_MAIN_NAVPATH:
            CONSOLE("click to navpath");
            setViewMainNavPath();
            break;
    }
}

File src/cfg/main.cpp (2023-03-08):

#include "main.h"
#include "../log.h"
#include "point.h"
#include "jump.h"
#include "webjoin.h"
#include "../navi/proc.h"
#include "../core/filebin.h"
#include "../view/base.h"
#include "../navi/compass.h"
#include "../net/bt.h"

#include <SPIFFS.h> // cfg reset default = format

template class Config<cfg_main_t>;
Config<cfg_main_t> cfg(PSTR(CFG_MAIN_NAME), CFG_MAIN_ID, CFG_MAIN_VER);

template class Config<cfg_point_t>; // Почему-то не линкуется, если эту строчку переместить в point.cpp

template class Config<cfg_jump_t>;

template class Config<cfg_webjoin_t>;

template class Config<cfg_magcal_t>;

/* ------------------------------------------------------------------------------------------- *
 *  Описание методов шаблона класса Config
 * ------------------------------------------------------------------------------------------- */

template <typename T>
Config<T>::Config(const char *_fname_P, uint8_t _cfgid, uint8_t _ver) :
    fname_P(_fname_P),
    cfgid(_cfgid),
    ver(_ver)
{
    reset();
}

template <typename T>
bool Config<T>::load() {
    if (!fileExists(fname_P)) {
        reset();
        _modifed = false;
        CONSOLE("config [%d] not exists: default", cfgid);
        return true;
    }
    
    FileBin f(fname_P);
    if (!f)
        return false;
    
    uint8_t h[2];
    size_t sz = f.read(h, 2);
    if (sz != 2) {
        CONSOLE("config [%d] header fail: %d of %d", cfgid, sz, 2);
        f.close();
        return false;
    }
    
    uint8_t id1 = h[1] >> 5;
    uint8_t ver1 = h[1] & 0x1f;
    if ((h[0] != CFG_MGC) || (id1 != cfgid) || (ver1 == 0)) {
        CONSOLE("config [%d] is not valid: mgc=0x%02x, h2=0x%02x, cfgid=%d, ver=%d", cfgid, h[0], h[1], id1, ver1);
        reset();
        f.close();
        return false;
    }
    
    if (ver1 > ver) {
        CONSOLE("config [%d] version later: ver=%d", cfgid, ver1);
        reset();
        f.close();
        return false;
    }
    
    if (ver1 < ver) {
        CONSOLE("config [%d] version earler: ver=%d", cfgid, ver1);
        uint8_t buf[sizeof(T)*2];
        if (!f.get(buf, sizeof(buf))) {
            f.close();
            return false;
        }
        upgrade(ver1, buf);
    }
    else {
        T d;
        if (!f.get(d, false)) {
            f.close();
            return false;
        }
        data = d;
    }

    f.close();
    
    CONSOLE("config [%d] read ok", cfgid);
    
    _modifed = false;
    _empty = false;
    return true;
}

template <typename T>
bool Config<T>::save(bool force) {
    if (!force && !_modifed) {
        //CONSOLE("config [%d] not changed", cfgid);
        return true;
    }

    if (fileExists(fname_P) && !fileRemove(fname_P)) {
        CONSOLE("config [%d] remove fail", cfgid);
        return false;
    }
    
    FileBin f(fname_P, FileMy::MODE_WRITE);
    if (!f)
        return false;

    uint8_t h[2] = { CFG_MGC, static_cast<uint8_t>((cfgid << 5) | (ver & 0x1f)) };
    
    size_t sz = f.write(h, 2);
    if (sz != 2) {
        CONSOLE("config [%d] header fail: %d of %d", cfgid, sz, 2);
        f.close();
        return false;
    }
    
    if (!f.add(data)) {
        f.close();
        return false;
    }
    
    f.close();
    
    CONSOLE("config [%d] saved OK", cfgid);
    
    _modifed = false;
    return true;
}

template <typename T>
void Config<T>::reset() {
    T d1;
    data = d1;
    _modifed = true;
    _empty = true;
}

template <typename T>
void Config<T>::upgrade(uint8_t v, const uint8_t *d) {
    memcpy(&data, d, sizeof(data));
}



template <typename T>
uint32_t Config<T>::chksum() const {
    uint32_t sz = sizeof(data);
    const uint8_t *d = reinterpret_cast<const uint8_t *>(&data);
    
    uint16_t cka = 0, ckb;
    for (int i=0; i<sz; i++) {
        cka += d[i];
        ckb += cka;
    }
    
    return (cka << 16) | ckb;
}

bool cfgLoad(bool apply) {
    bool ok = true;
    if (!cfg.load())
        ok = false;
    if (!pnt.load())
        ok = false;
    if (!jmp.load())
        ok = false;
    
    if (apply) {
        displayContrast(cfg.d().contrast);
        displayFlipp180(cfg.d().flipp180);
        btnFlipp180(cfg.d().flipp180);
        if (cfg.d().navonpwron)
            gpsOn(NAV_PWRBY_PWRON);
        
#ifdef USE_BLUETOOTH
        if ((cfg.d().net & 0x1) > 0)
            bluetoothStart();
#endif // #ifdef USE_BLUETOOTH
    }
    
    return ok;
}
bool cfgSave(bool force) {
    return
        cfg.save(force) &&
        pnt.save(force) &&
        jmp.save(force);
}

bool cfgFactory() {
    /*
    cfg.reset();
    pnt.reset();
    jmp.reset();
    
    return cfgSave(true);
    */
    SPIFFS.end();
    CONSOLE("SPIFFS Unmount ok");
    if (!SPIFFS.format()) {
        CONSOLE("SPIFFS Format Failed");
        return false;
    }
    CONSOLE("SPIFFS Format ok");

    if(!SPIFFS.begin()) {
        CONSOLE("SPIFFS Mount Failed");
        return false;
    }
    CONSOLE("SPIFFS begin ok");
    
    return cfgLoad(true);
}

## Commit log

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2020-05-27 factory reset - доработки сброса текущего экрана в mode-main
    [main.cpp]
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2021-02-13 начата разработка платы - пока рисуем схему - основная обвязка esp32, кнопки, интерфейс прошивки, вывод на дисплей
    [gpsalthw.sch]
2021-02-13 схема - добавлен модуль зарядки
    [gpsalthw.sch]
2021-02-13 схема - добавлена схема питания
    [gpsalthw.sch]
2021-02-13 схема - поправлены посадочные места
    [gpsalthw.sch]
2021-02-13 схема - добавлен датчик давления
    [gpsalthw.sch]
2021-02-13 схема - добавлен ublox m8n
    [gpsalthw.sch]
2021-02-14 схема - доработана связка с ublox m8n
    [gpsalthw.sch]
2021-02-14 плата - очень примерно раскиданы элементы по группам и секторам
    [gpsalthw.kicad_pcb]
2021-02-14 плата - предварительно раскиданы элементы
    [gpsalthw.kicad_pcb, gpsalthw.sch]
2021-02-14 плата - добавлен усб-разъём
    [gpsalthw.kicad_pcb, gpsalthw.sch]
2021-02-21 плата - разведены дорожки
    [gpsalthw.kicad_pcb, gpsalthw.sch]
2021-02-22 плата - добавлен разъём для батареи, serial-разъём заменён на micro jst, оптимизированы некоторые дорожки (убраны лишние переходы между слоёв)
    [gpsalthw.kicad_pcb, gpsalthw.sch]
2021-02-23 плата - поправлен косяк с питанием дисплея
    [gpsalthw.kicad_pcb, gpsalthw.sch]
2021-02-23 плата - нормально оформлены mounting pin у раъёмов к батарее и serial
    [gpsalthw.kicad_pcb, gpsalthw.sch]
2021-02-23 плата - поправлены некоторые надписи
    [gpsalthw.kicad_pcb]
2021-02-24 схема/плата - добавлены кондецаторы по питанию
    [gpsalthw.kicad_pcb, gpsalthw.sch]
2021-03-07 hw - перевернут вовнутрь разъём serial и кнопки заменены на более маленькие
    [gpsalthw.kicad_pcb, gpsalthw.sch]
2021-03-08 hw - добавлены пвторители кнопок другого размера посадочных мест
    [gpsalthw.kicad_pcb, gpsalthw.sch]
2021-03-09 плата - разъёмы батареи и serial заменены на более правильные
    [gpsalthw.kicad_pcb, gpsalthw.sch]
2021-03-16 плата - поправлены кнопки reset/boot
    [gpsalthw.kicad_pcb, gpsalthw.sch]
2021-03-16 плата - доработаны надписи
    [gpsalthw.kicad_pcb]
2021-03-30 плата - собран набор gerber для печати
    [gpsalthw.kicad_pcb]
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2021-04-25 корпус - freecad версия
    [gpsadv.FCStd]
2021-04-25 корпус - переименованы нормально все объекты, поправлены мелкие баги, скруглены края для нижней крышки, экспортированы stl
    [gpsadv-box-bottom.stl, gpsadv-box-top.stl, gpsadv.FCStd]
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2021-04-27 box - поправлены баги
    [gpsadv-box-bottom.stl, gpsadv-box-top.stl, gpsadv.FCStd]
2021-04-28 box - верхняя часть перерисована в sketchup
    [gpsadv-box-top.stl, gpsadv.skp]
2021-04-28 box - доделаны скругления на top-стороне, переделана в sketchup bottom-сторона, добавлен вариант bottom-bold для более толстого аккума
    [gpsadv-box-bottom-bold.stl, gpsadv-box-bottom.stl, gpsadv-box-top.stl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]
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2021-06-02 архив v0.3 - плата + корпус
    [gpsadv-box-bottom-bold.stl, gpsadv-box-bottom.stl, gpsadv-box-top.stl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]
2021-06-02 схема - дисплей переделан под 24pin fpc
    [gpsalthw.sch]
2021-06-02 вместо кнопок и разъёма программирования - добавлен cp2102
    [gpsalthw.sch]
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2021-06-24 схема - под большой экран, usb-uart
    [gpsalthw.sch]
2021-06-24 плата - контур платы, отверстия, примерно раскиданы элементы
    [gpsalthw.kicad_pcb]
2021-06-24 плата - расставлены компоненты выше разъёма дисплея (верхняя половина платы)
    [gpsalthw.kicad_pcb, gpsalthw.sch]
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2021-08-11 плата - исправлены проблемы подключения uart
    [gpsalthw.kicad_pcb, gpsalthw.sch]
2021-08-12 box - переделываем под v.0.4 - общий каркас обеих половинок, отверстие под экран
    [gpsadv.skp]
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2021-08-29 плата - доработана развязка uart + мелкие доработки, сформирован архив для печати v.0.4.1
    [gpsadv-noroundcorner.skp, gpsalthw.kicad_pcb, gpsalthw.sch]
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2021-09-27 box - поправлен косяк вырезов под антенну и чуть расширено окно usb
    [gpsadv-box-bottom.stl, gpsadv-box-top.stl, gpsadv-noroundcorner.skp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]
2021-09-28 box - поправлено отверстие под экран, отверстие под usb, добавлена версия с креплением шнуром
    [gpsadv-box-bottom-cord.stl, gpsadv-box-bottom-lent.stl, gpsadv-box-bottom.stl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]
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2021-10-14 ожидание отпускания кнопки при factory reset, т.к. при возникновении прерывания происходит паника - в будущем надо отключать прерывания при доступе к файловой системе и при работе с вифи
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2021-10-25 на экране вместо количества спутников отображать fail, если давно не было данных или модем не проинициализировался
    [proc.h]
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2021-11-27 удлинённый корпус v.0.4 (вынести патч-антенну + место под проволочную антенну)
    [xdeya-long-box-bottom-lent.stl, xdeya-long-box-top.stl, xdeya-long-noroundcorner.skp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]
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2022-03-18 удлинённый корпус под v.0.4 - небольшие доработки по задней крышке
    [xdeya-box.v0.4.1-long-bottom-cord.stl, xdeya-box.v0.4.1-long-bottom-lent.stl, xdeya-box.v0.4.1-long-top.stl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]
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2022-06-12 корпус - для варианта с лентами на руку уменьшена глубина (теперь такая же, как у варианта со шнуром на ногу)
    [xdeya-box-int-bottom-lent.stl, xdeya-int-noroundcorner.skp, xdeya-int.skp]
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2022-09-22 box - по длинной стороне сделан жолоб для более стабильного сочленения сторон
    [xdeya-box-int-bottom-cord.stl, xdeya-box-int-bottom-lent.stl, xdeya-box-int-top.stl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]
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2023-09-05 hw - доделана трассировка платы, но скорее всего, придётся всё переделывать, слишком много пересечений
    [xdeya.kicad_pcb, xdeya.kicad_sch]
2023-09-07 hw - переделана трассировка платы, стало лучше, осталось: расставить шелкографию, проверить, наделать переходных по gnd
    [xdeya.kicad_pcb, xdeya.kicad_sch]
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2023-09-08 hw - оптимизированы дорожки, добавлены переходные между gnd
    [xdeya.kicad_pcb]
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
